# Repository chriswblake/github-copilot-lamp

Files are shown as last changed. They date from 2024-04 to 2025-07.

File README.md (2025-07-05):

# GitHub Copilot Lamp
A fun and playful lamp to match the energy of [GitHub Copilot](https://github.com/features/copilot). It's 3d printable, fairly easy to assemble, WiFi connected and powered by [WLED](https://kno.wled.ge/) and touch!

> This project was inspired by the original [Octolamp](https://github.com/martinwoodward/octolamp). Go check it out!

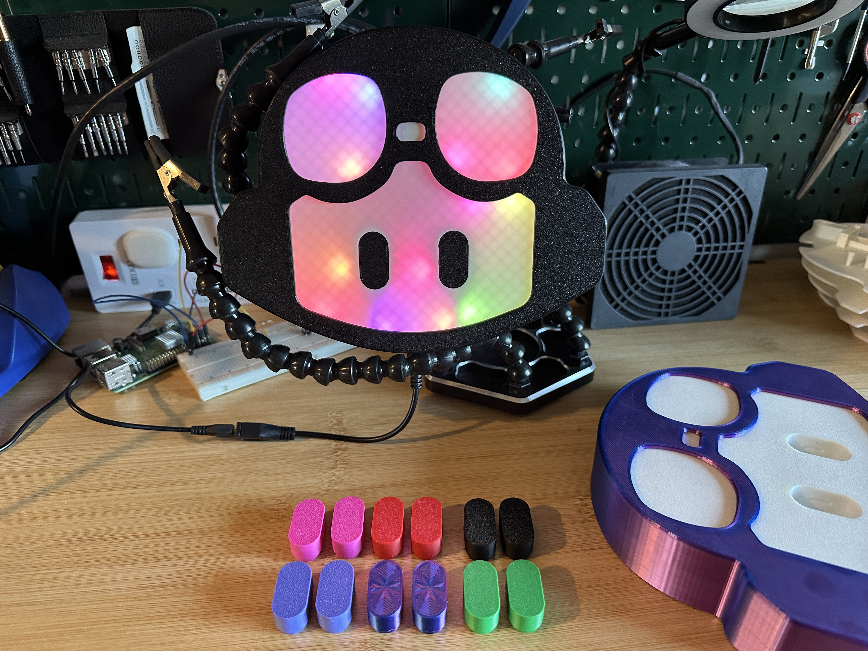
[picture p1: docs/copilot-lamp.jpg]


## How to Use
If you received your lamp prebuilt, is has already been configured and is ready to use. Simply plug it in with a USB cable and power brick with at least 1 amp. The lamp will turn on with an "aurura" like green effect.

### How to Turn on/off
The white spot between the goggles is a touch sensor and provides basic control the lamp. For more advanced control, you can use the WLED app or web interface!

- Automatically turns on at 9am CST.
- Automatically turns off at 5pm CST.

| Single Press | Double Press | Long Press |
| - | - | - |
| Slow Fade Green | Fast Random Rainbow | Off |
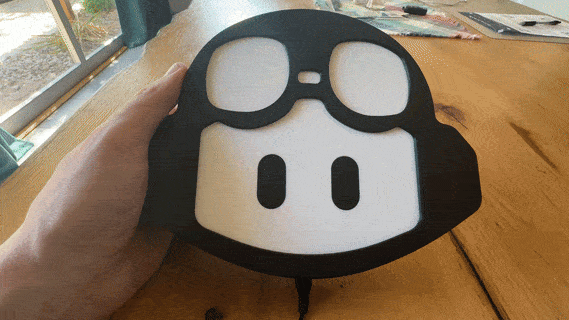
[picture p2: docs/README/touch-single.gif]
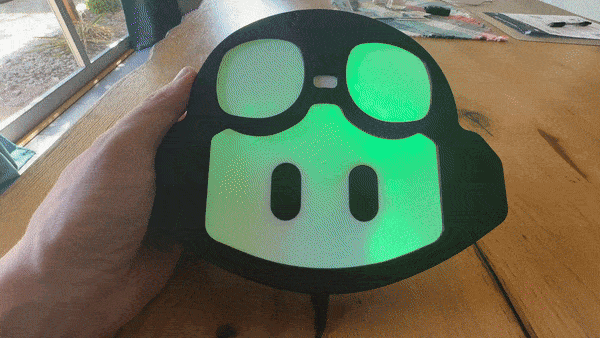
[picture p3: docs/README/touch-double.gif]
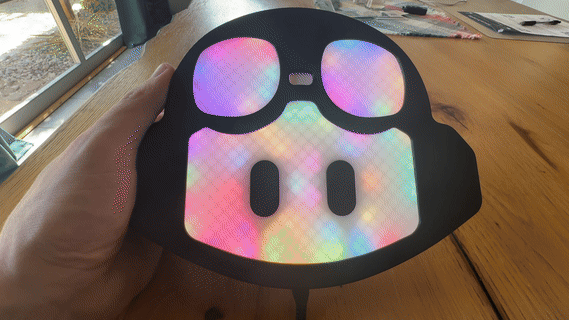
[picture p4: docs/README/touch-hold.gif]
|  |  |  |

### Connect to WiFi
Want full control over your lamp? Connect it to your WiFi network! (2.4ghz only)
If not connected to an existing wifi, it will broadcast a tempory wifi network for setup.

1. On your phone or computer, search for the wifi network `copilot-lamp` and connect to it.
    - Default password is `copilot-lamp` or `wled1234`.
1. Wait a moment and a temporary login-style web browser will appear. If no browser appears, open a web browser navigate to http://copilot-lamp.local.
1. In the top right, click the **Config** gear icon to open the settings menu.
1. Select **WiFi Setup**.
1. Enter you home's wifi name and password. Click **Save & Connect**. Wait a moment for the lamp to restart.
1. Reconnect your phone or computer to your home wifi.
1. Now when connected to your home wifi, you can use the WLED app.
    - [iOS App](https://apps.apple.com/us/app/wled/id1475695033)
    - [Android App](https://play.google.com/store/apps/details?id=com.aircoookie.WLED)
    - Alternately, the lamp can still be accessed in  a web browser by navigating to http://copilot-lamp.local.

<div>
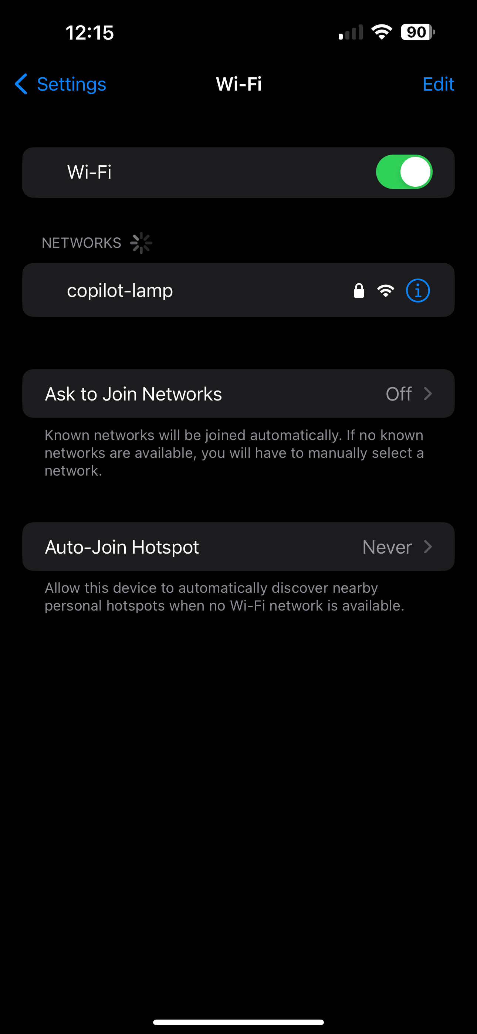
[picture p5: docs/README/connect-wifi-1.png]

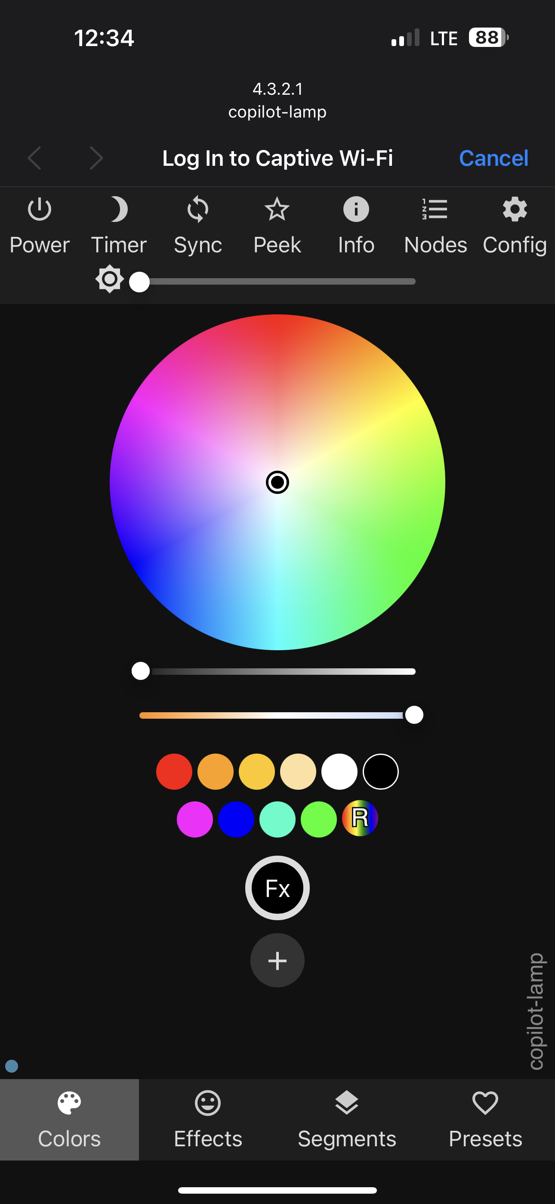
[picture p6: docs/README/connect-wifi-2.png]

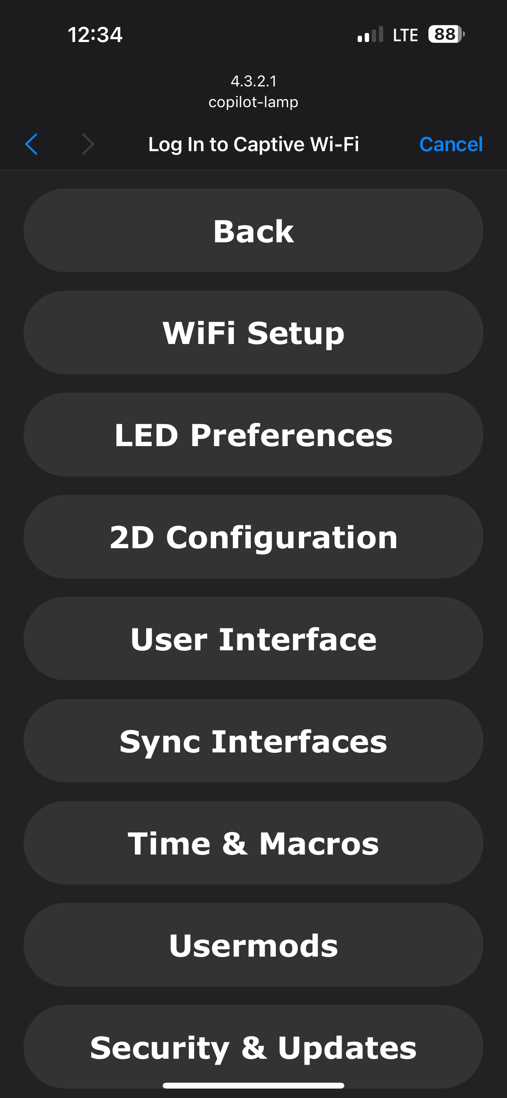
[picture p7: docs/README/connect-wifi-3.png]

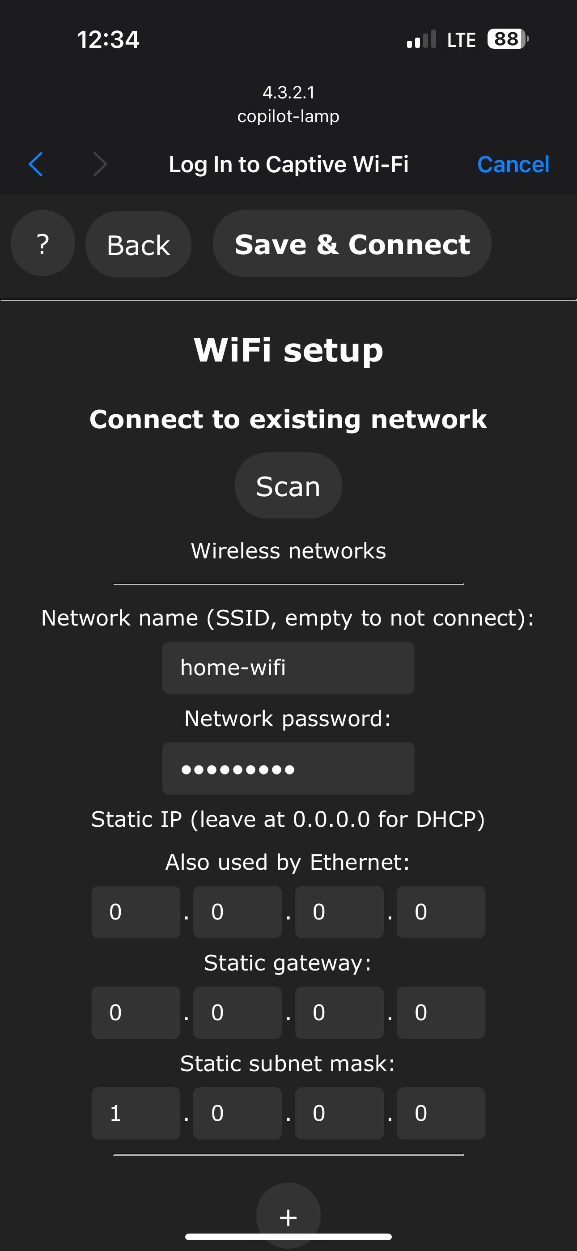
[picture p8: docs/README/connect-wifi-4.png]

</div>

### Change eye color

1. Using a screwdriver, insert the end through the holes in the back of the lamp.  
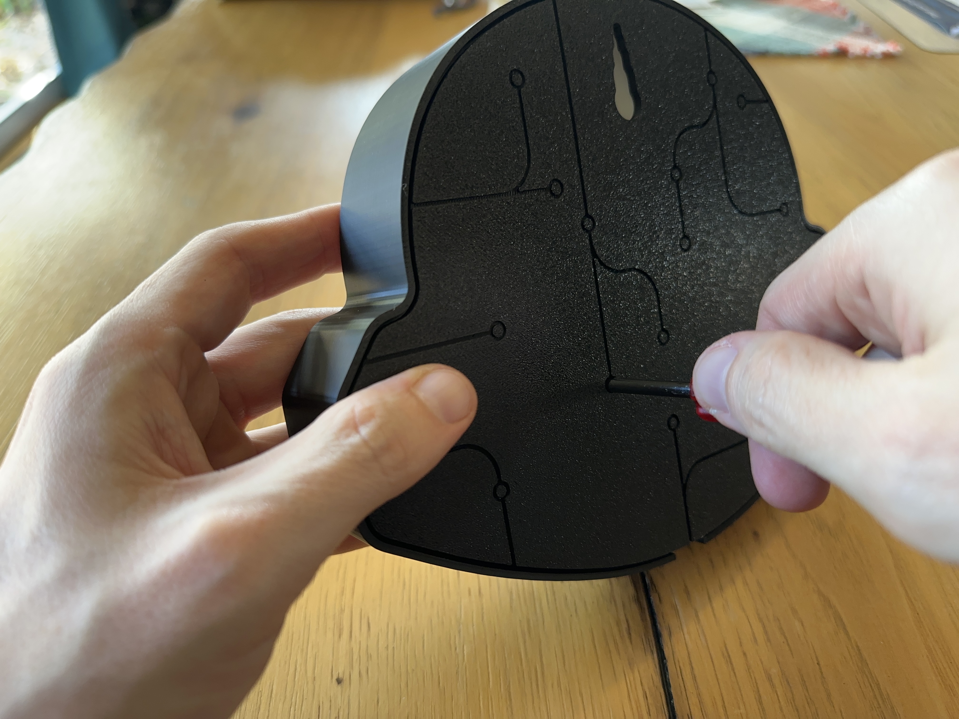
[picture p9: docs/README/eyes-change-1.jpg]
    

1. Continue to push and the eye insert will pop forward.  
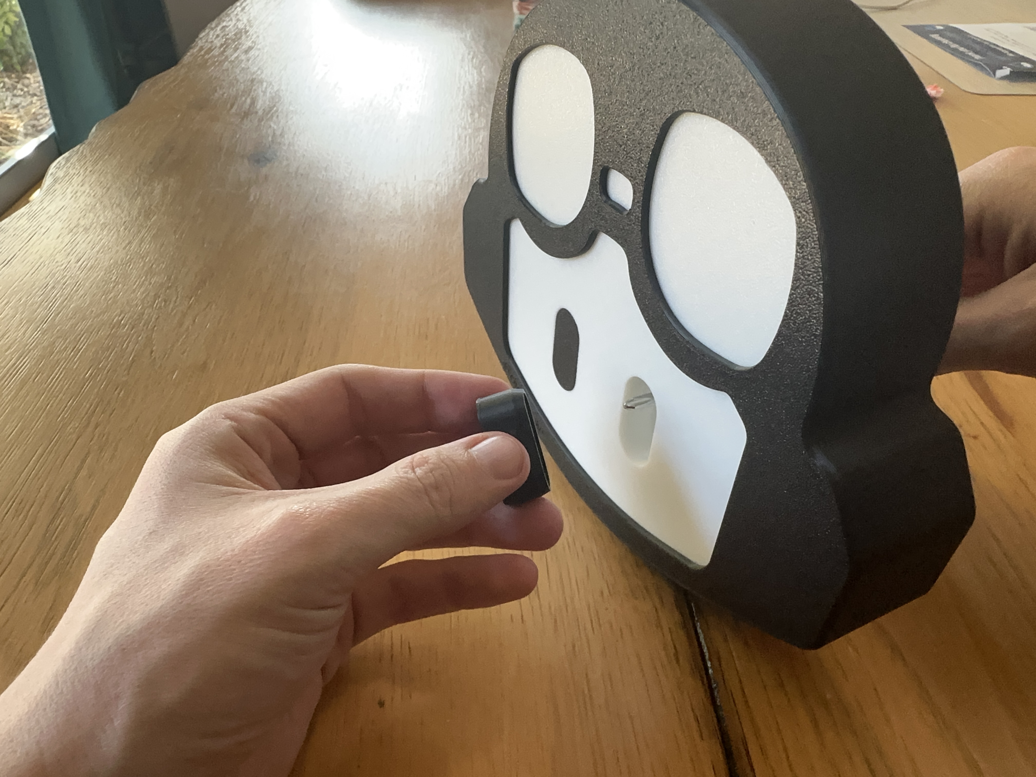
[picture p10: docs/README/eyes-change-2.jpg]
    

1. Insert the other colored eyes!

### Change helmet color (faceplate)

1. Grip the top of the mask and gently push into the white space of the goggles. You will feel the connectors pop out.  
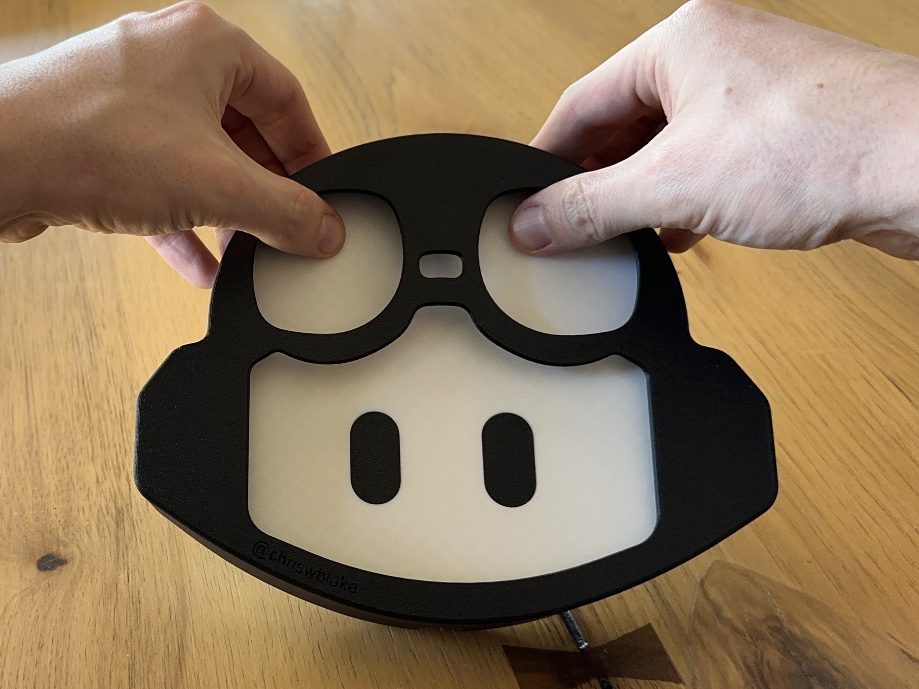
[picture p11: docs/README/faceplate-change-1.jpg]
    

1. Flip the lamp over, and repeat on the other side. Once disconnected, slide the faceplate off.

1. Apply the new faceplate!

## Troubleshooting

### Can't connect to WiFi.
If you aren't able to connect to 'copilot-lamp' or you locked yourself out by entering bad wifi information, you can update the wifi information at the WLED website.

1. Connect the device to your computer using a USB cable.
1. Click 'Install' button. It will detect the lamp already has WLED installed and provide options.
1. Select 'Change WI-FI' and it will scan for nearby options.
1. Enter your wifi password and wait a moment.
1. Click 'Visit Device' and it will navigate to the webpage view.

# Build your own 🤓
That's cool and all, but how do I make one?!  
Check out the [build your own](docs/build-your-own.md) page for a step-by-step guide. 🧑‍🚀

Making it for someone else? How kind of you! 💚 Check out the [gift a friend](docs/gift-a-friend.md) page to create an awesome unboxing experience! 🤩

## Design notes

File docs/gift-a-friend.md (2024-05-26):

# Guide: Gift a friend 💚
The copilot lamp is meant to be shared, and... who doesn't want an awesome unboxing experience. 🥰

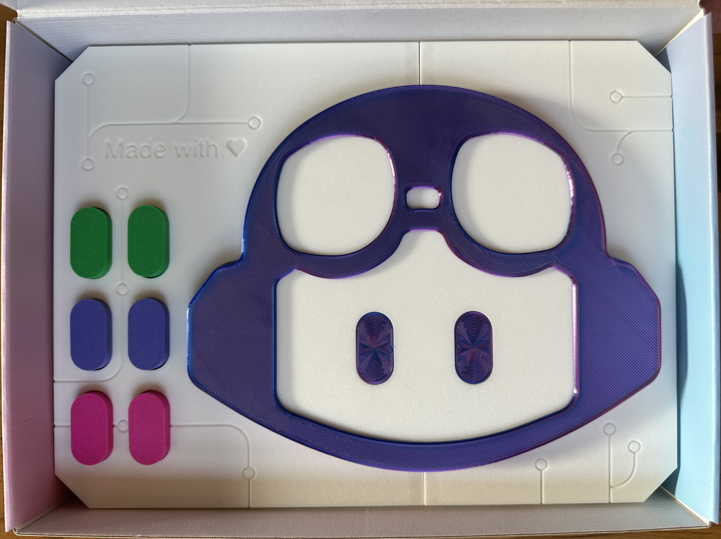
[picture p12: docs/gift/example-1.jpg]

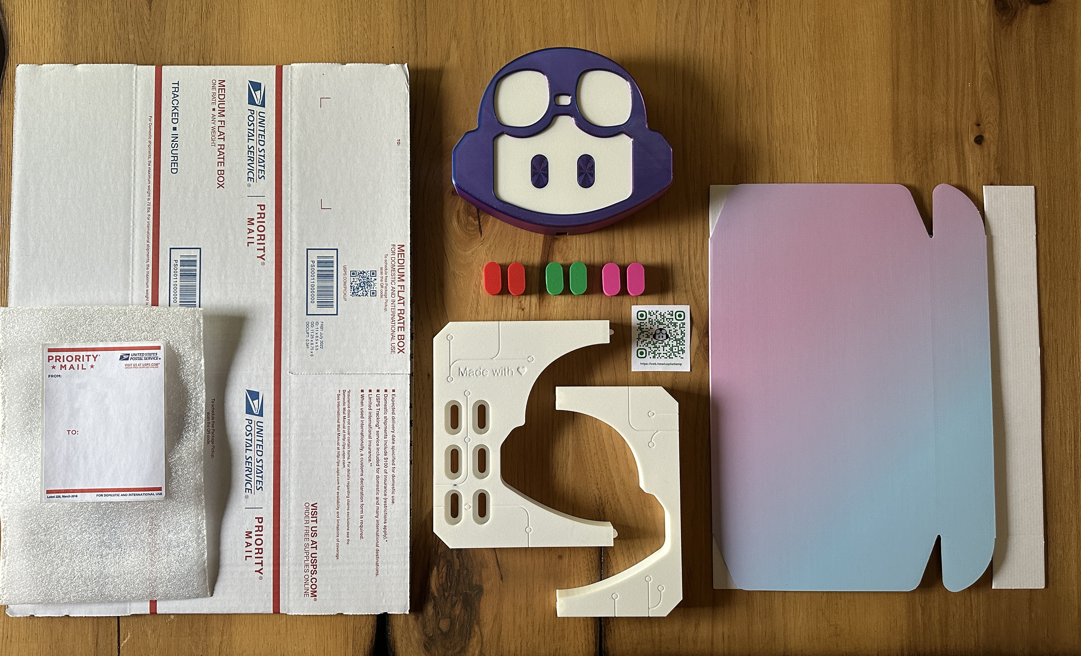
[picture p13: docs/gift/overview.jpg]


### Materials
- White PLA Filament [[US]](https://us.store.bambulab.com/products/pla-basic-filament?variant=41078274687112)
- Beautiful Gradient Purple Box (11x8x2) [[US]](https://www.amazon.com/dp/B0B7JB5KC9)
- USPS Medium Size Shipping Box, Top Loading [[US]](https://store.usps.com/store/product/shipping-supplies/priority-mail-flat-rate-medium-box-1-P_O_FRB1)
- Packing Foam
- Packing Tape

# Instructions

## 1. Print the parts
The .STL files for all of the printable shipping protector are in the `/models` folder.

- No supports are required.
- Any infill is fine. No special settings are required.
- For a matte look, consider a textured plate. [[US]](https://us.store.bambulab.com/products/bambu-dual-sided-textured-pei-plate)

| Image | Part | Description |
| -- | -- | -- |
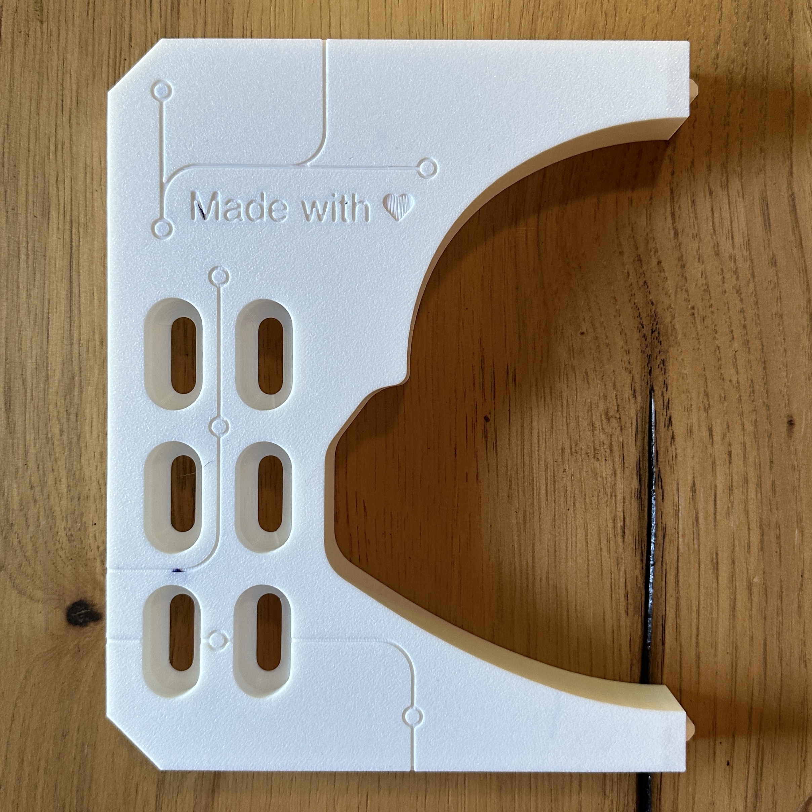
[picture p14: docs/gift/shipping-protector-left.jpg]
 | Shipping Protector (left) | Connects with the right piece to hold the position of the lamp in the box. Has slots for holding additional eye colors. Also indirectly teaches owner how to swap eyes colors. |
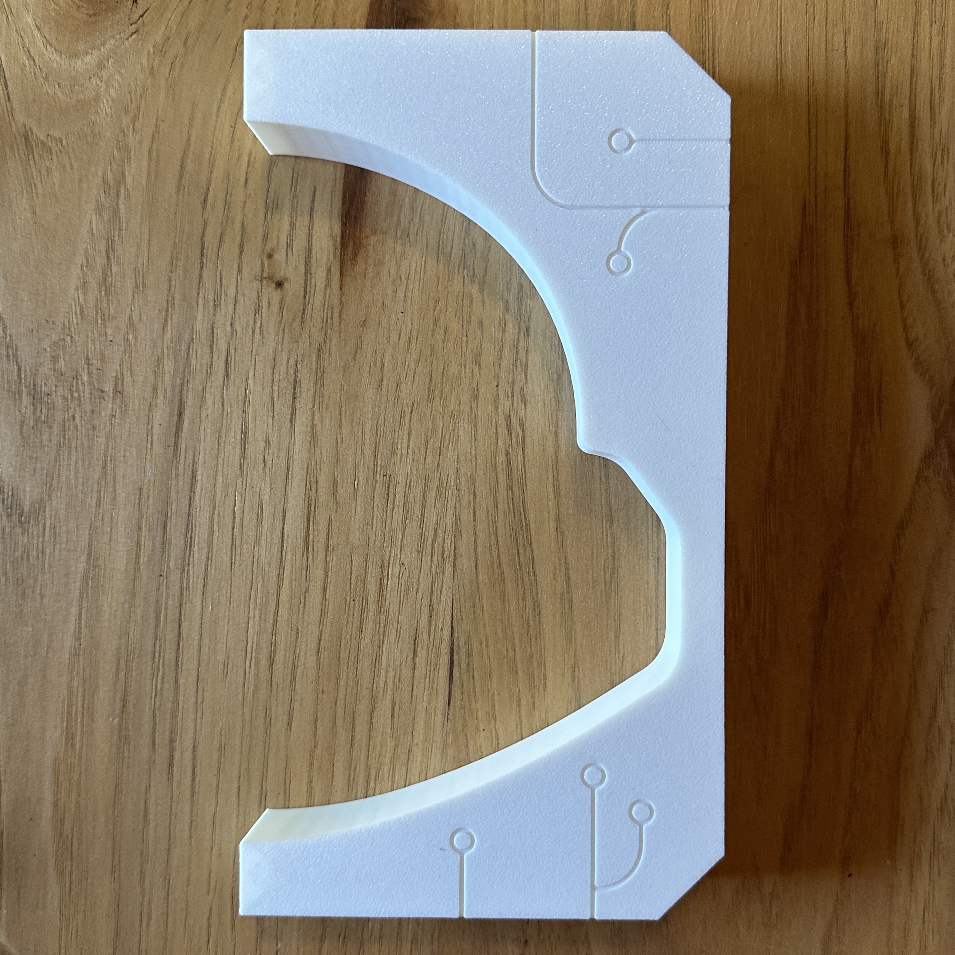
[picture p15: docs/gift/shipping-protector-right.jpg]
 | Shipping Protector (right) | Connects with the left piece to hold the position of the lamp in the box. |
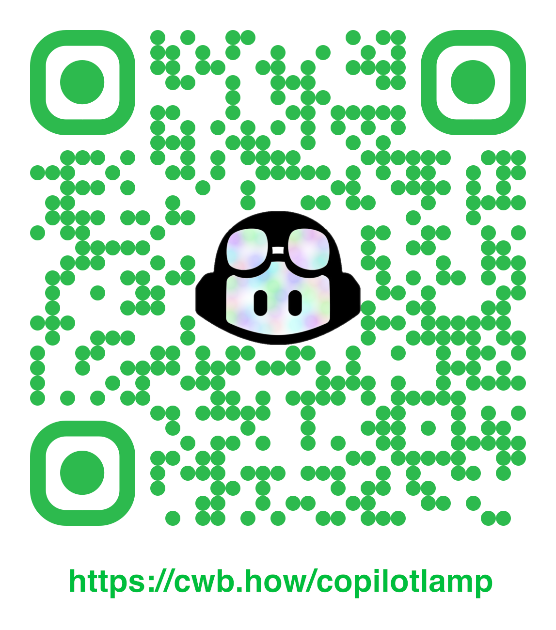
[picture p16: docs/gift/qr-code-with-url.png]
 | User Instructions QR Code | When scanned, directs user to main README for basic usage instructions. Obviously just normal 2D printing. 😉 |

## 2.  Prep the Copilot Lamp box

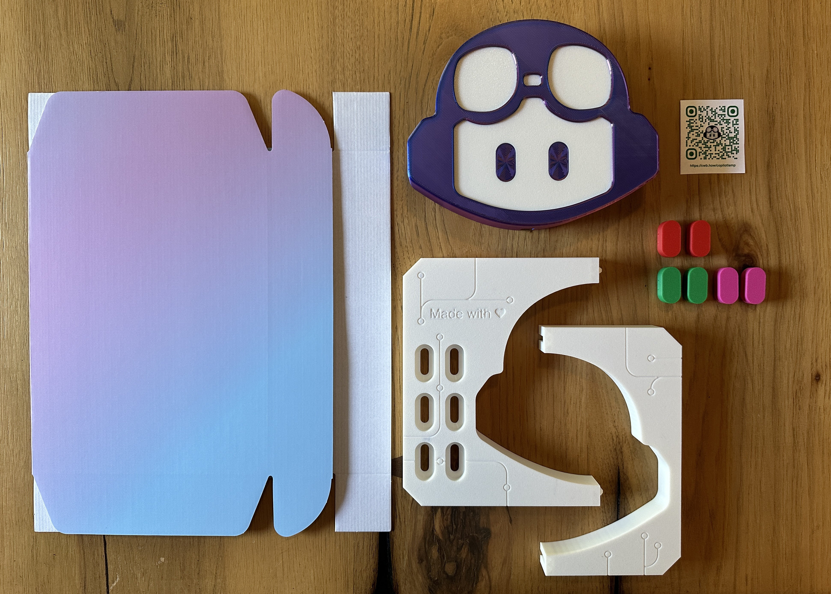
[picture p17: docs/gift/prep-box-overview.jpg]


1. Ensure the tabs of the front and back are inward and fold the sides down. The side's have tabs that slip into the slot to keep the shape.
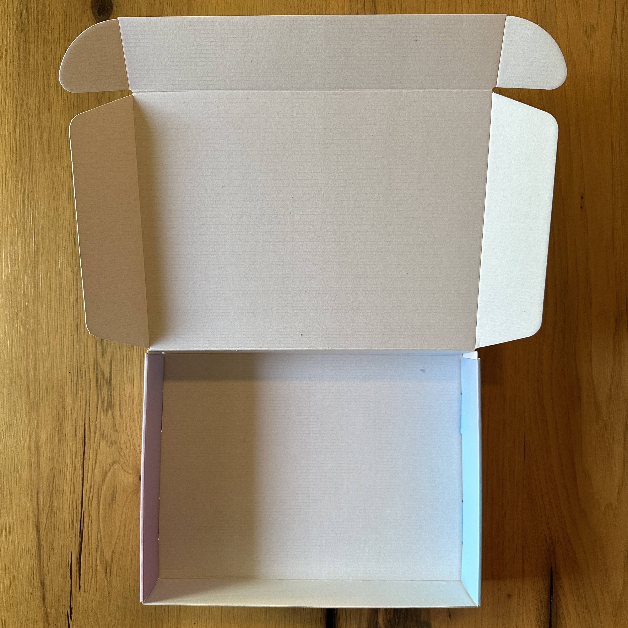
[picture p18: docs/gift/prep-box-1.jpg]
    

1. Connect the left shipping protector and right shipping protector together.
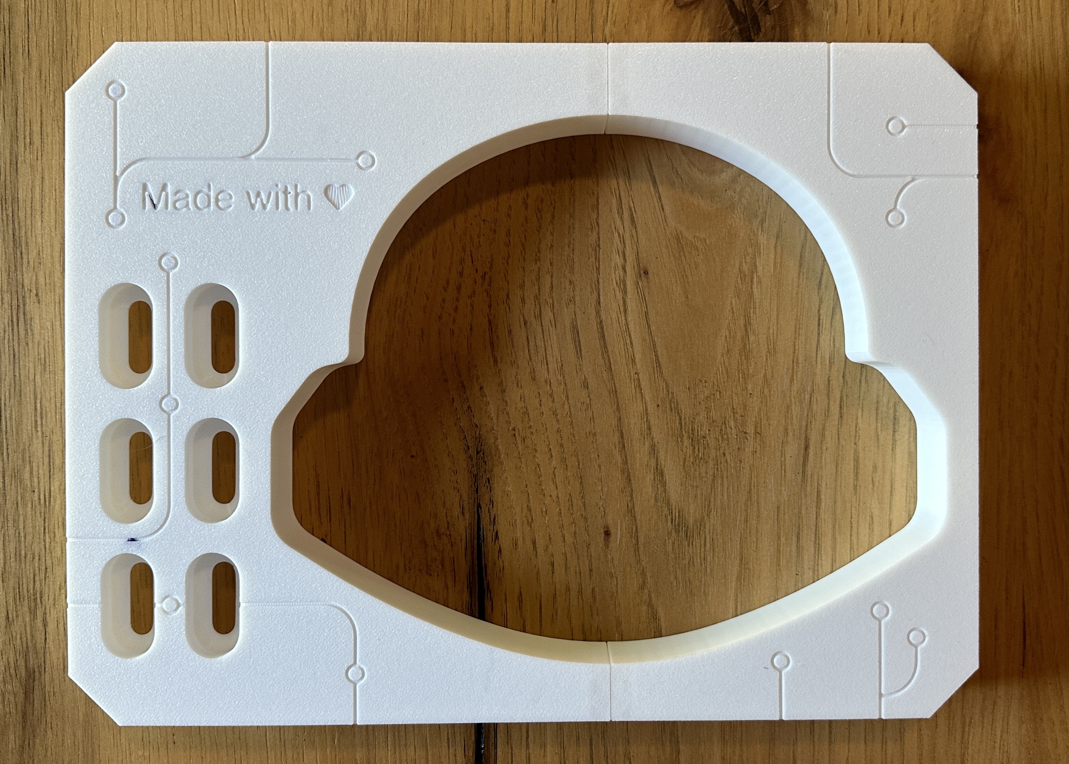
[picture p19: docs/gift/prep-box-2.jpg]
    

1. Insert the shipping connector into the box.
    > Note: It may appear loose. The gaps will be filled when the top is closed.
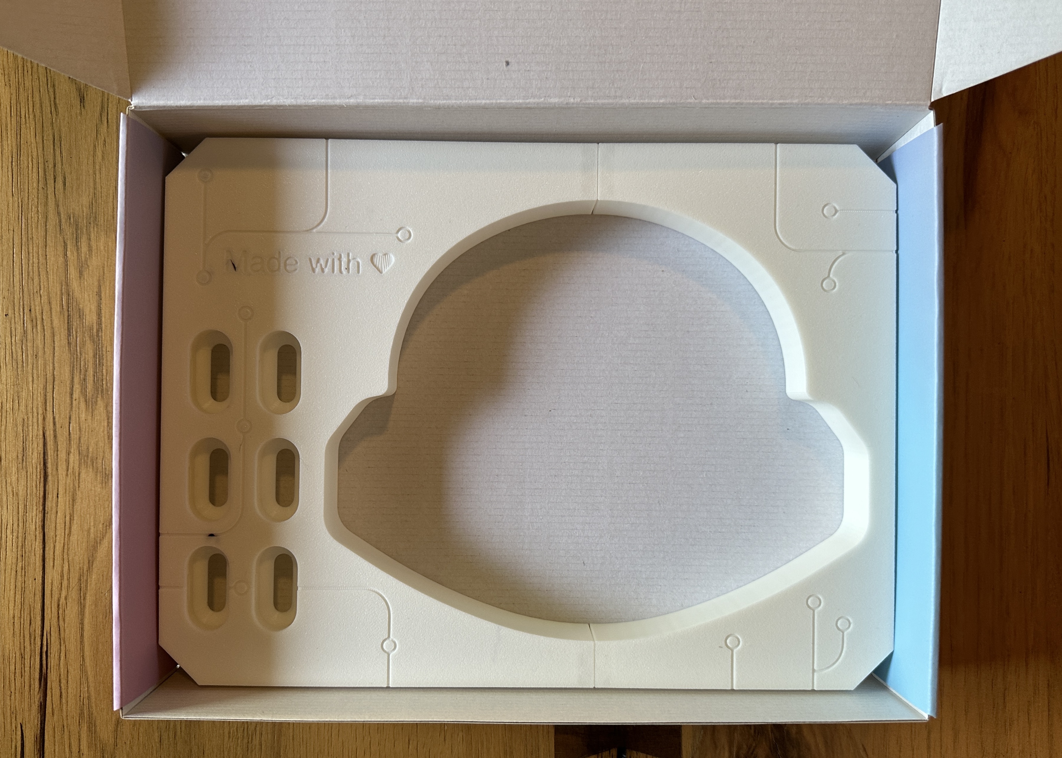
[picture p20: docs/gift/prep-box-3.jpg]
    

1. Insert the lamp.
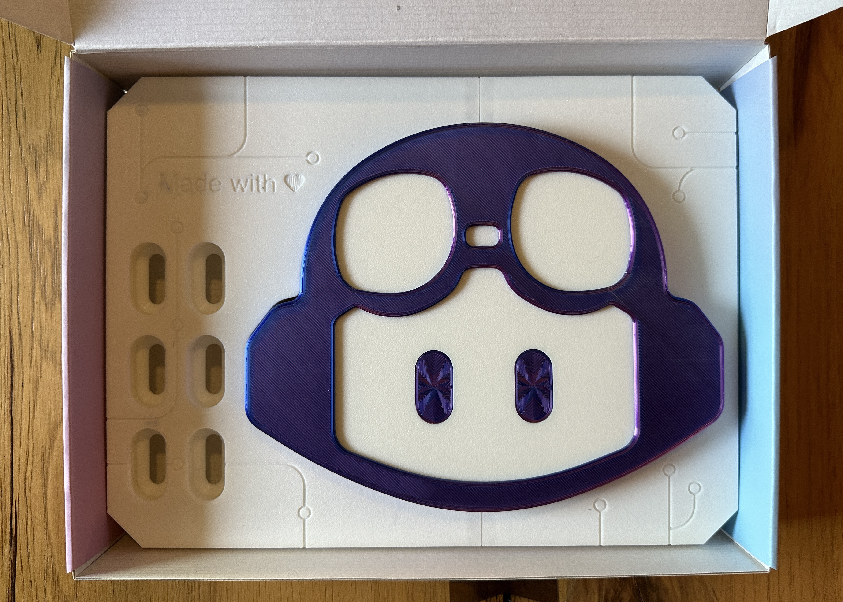
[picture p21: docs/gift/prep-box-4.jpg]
    

1. Pick some fun extra eye colors. Snap them into the holders.
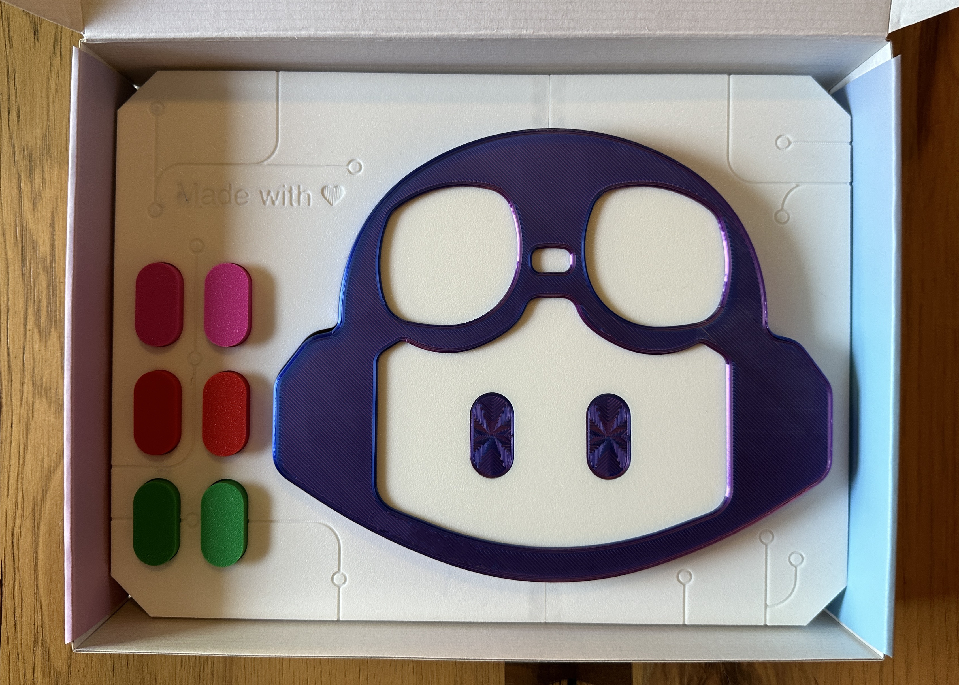
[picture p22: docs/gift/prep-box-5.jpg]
    

1. Add a sheet of protective foam.
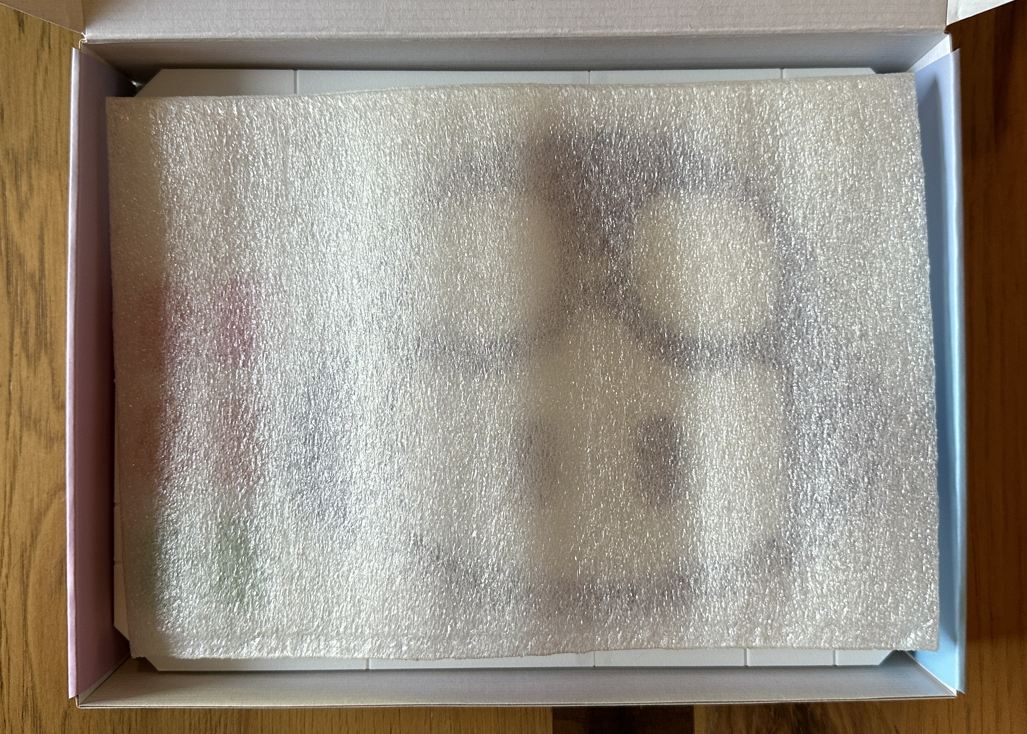
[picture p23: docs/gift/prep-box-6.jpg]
    

1. Add the QR Guide.
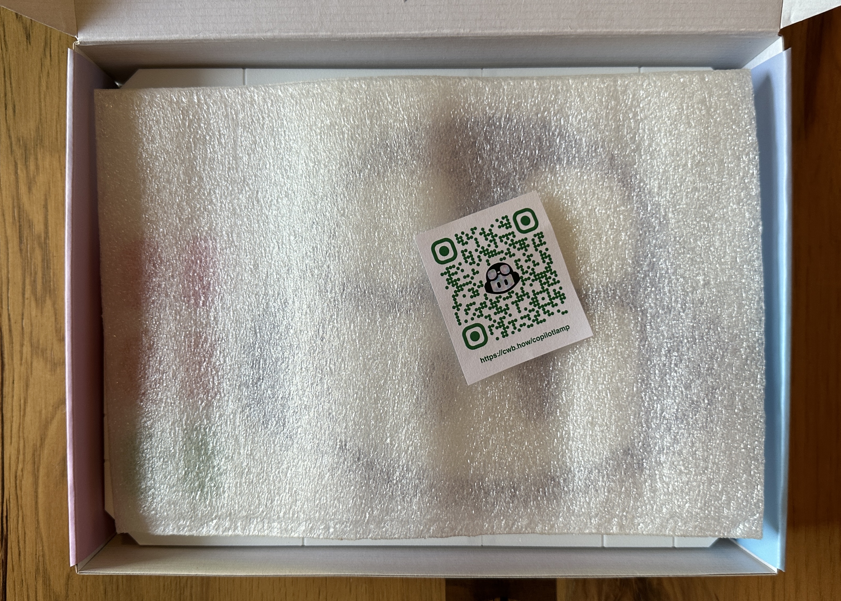
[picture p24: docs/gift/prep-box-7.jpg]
    

1. Close the box. Smile for a job well done! 🤓
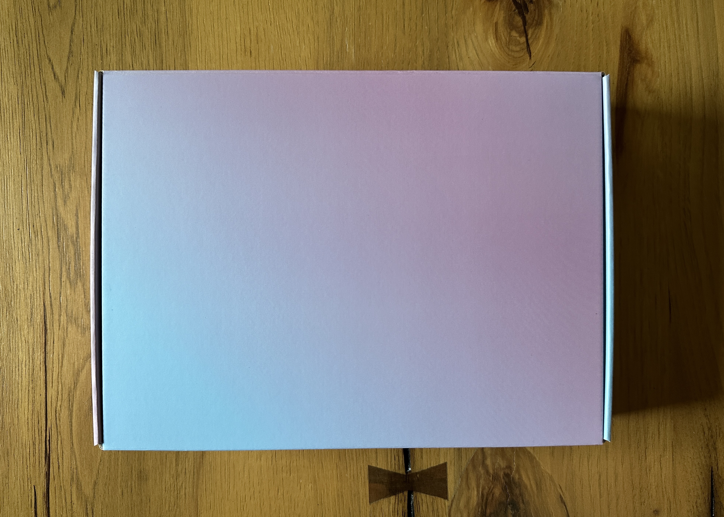
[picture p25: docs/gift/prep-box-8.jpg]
    

## 3. Ship the gift

1. Fold the USPS shipping box and tape the bottom side.
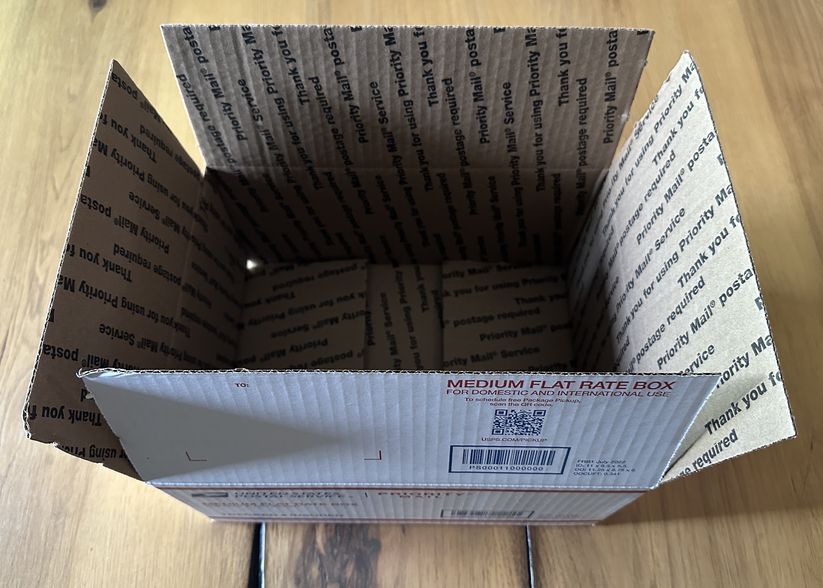
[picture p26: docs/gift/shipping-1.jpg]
    

1. Add some shipping protection to the bottom.
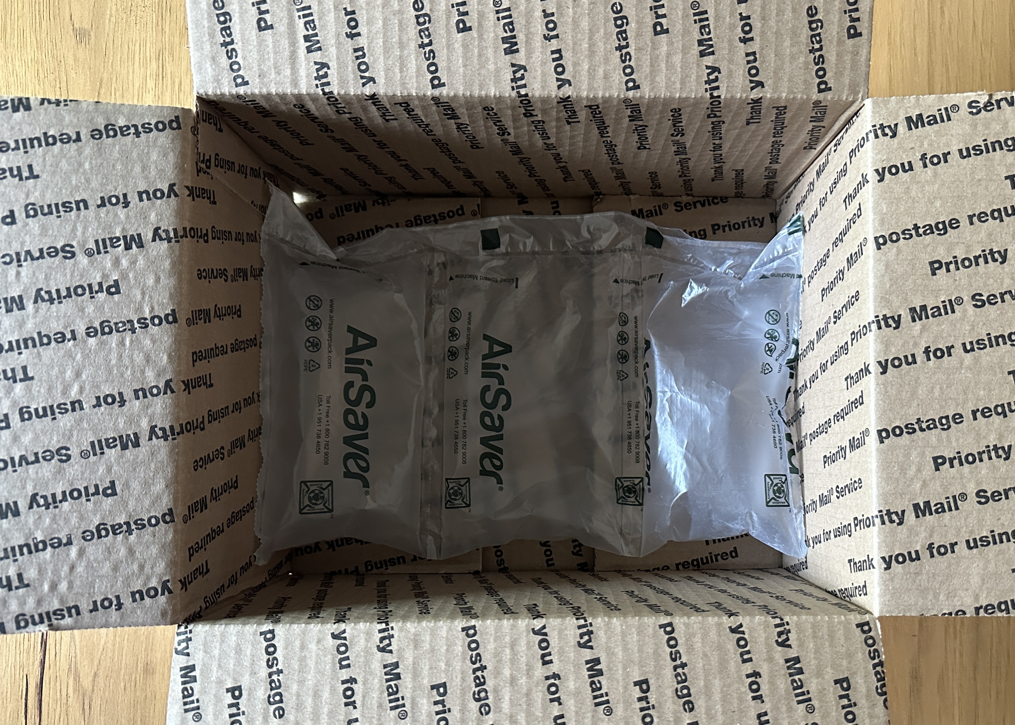
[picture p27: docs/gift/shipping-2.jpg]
    

1. Insert the box with your GitHub Copilot lamp.
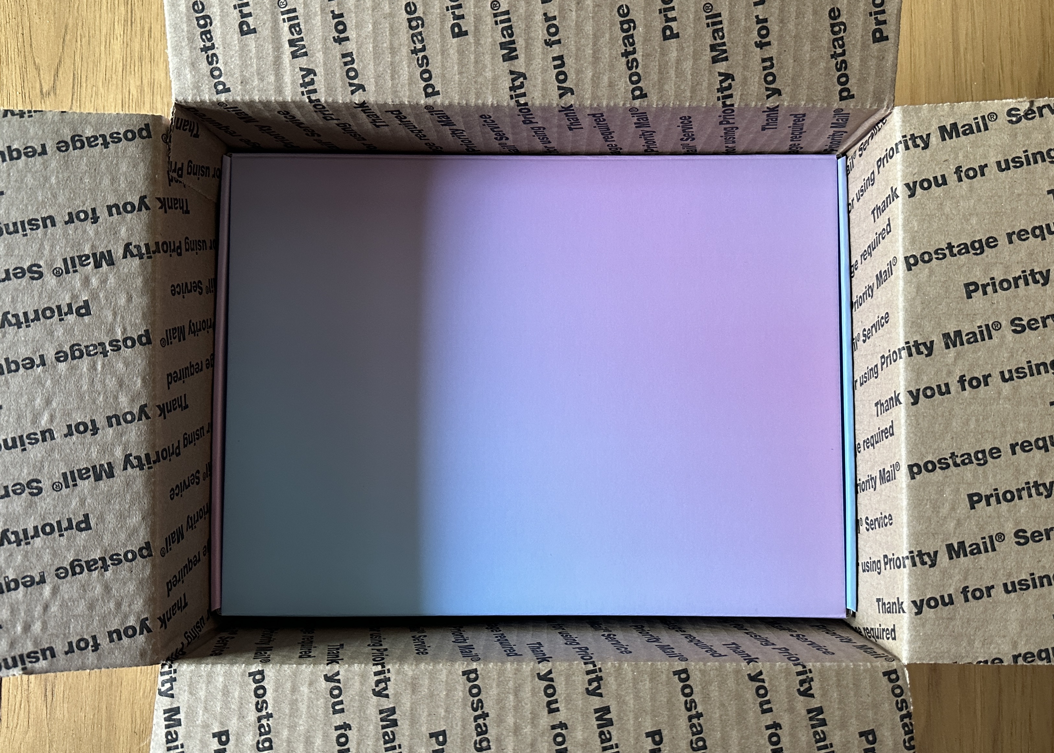
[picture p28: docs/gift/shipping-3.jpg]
    

1. Add some more shipping protection.
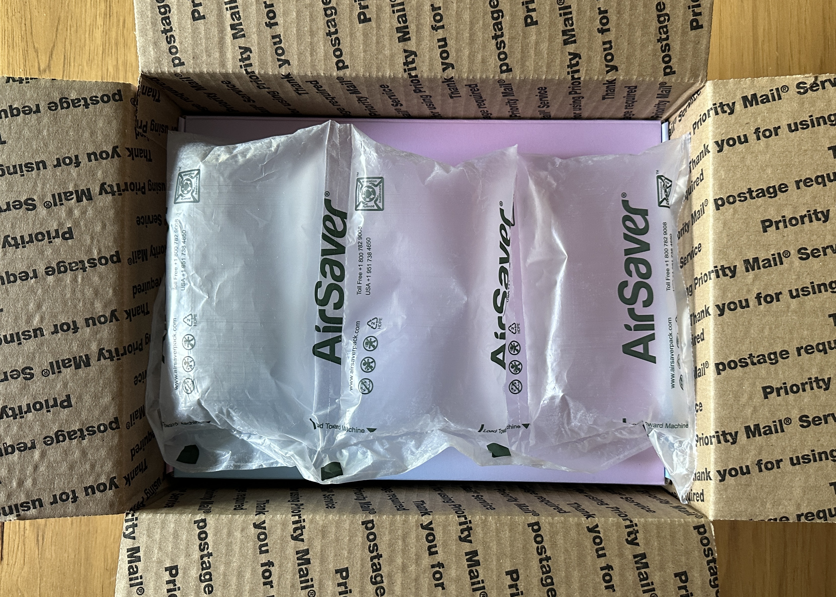
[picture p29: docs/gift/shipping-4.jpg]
    

1. Close the box folds and tape it shut.
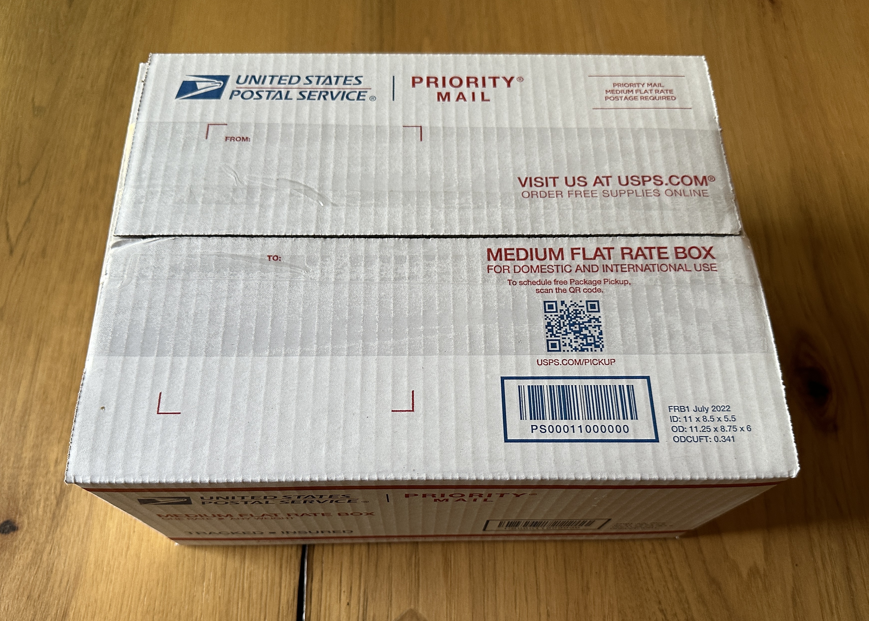
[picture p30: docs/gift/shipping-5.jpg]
    

1. Fill out the address sticker.
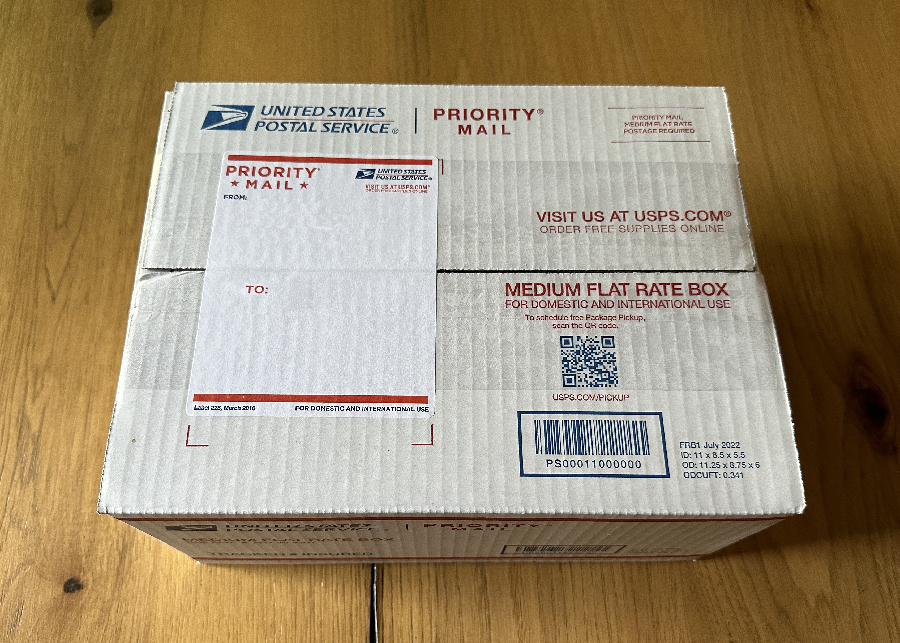
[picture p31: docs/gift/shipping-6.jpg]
    

1. Take it to the post office!

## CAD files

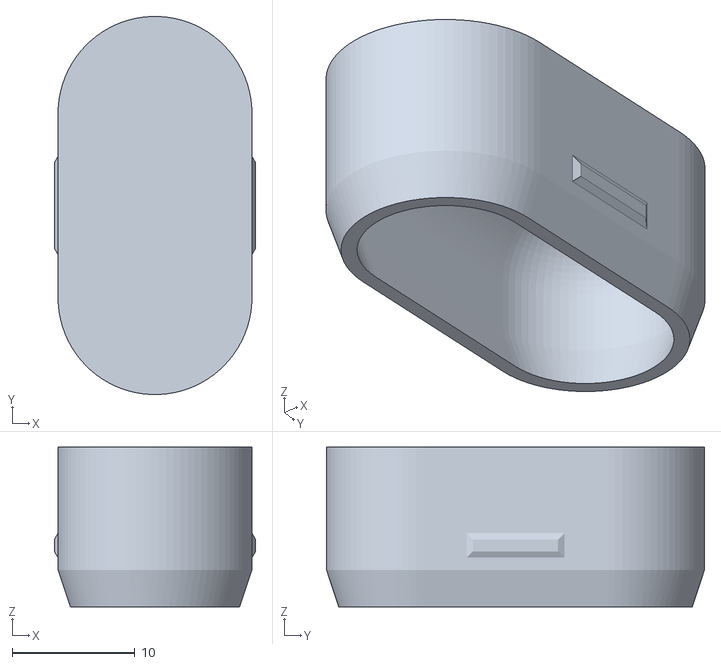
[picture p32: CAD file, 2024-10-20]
models/eye.stl
16.4 x 30.8 x 13.0

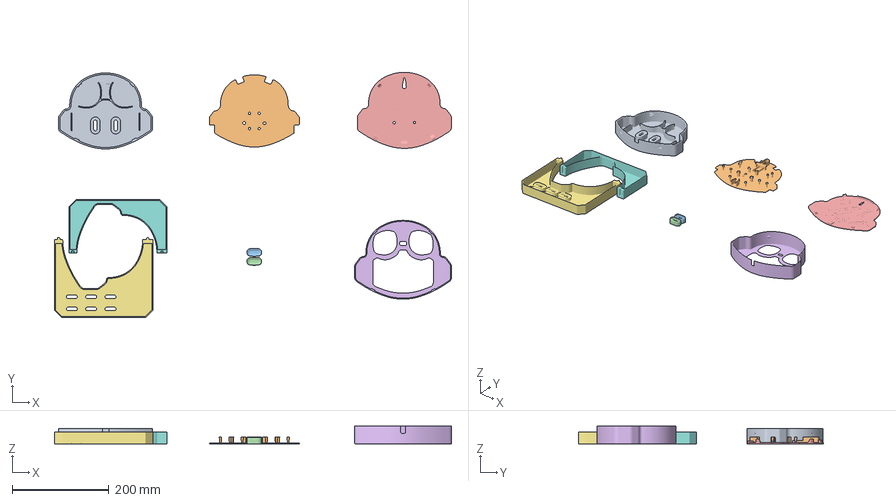
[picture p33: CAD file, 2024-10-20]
models/gh-copilot-lamp.3mf
819.8 x 506.6 x 37.0 mm
led-chamber.stl
electronics-plate.stl
eye.stl x 2
backplate.stl
faceplate.stl
shipping-protector-left.stl
shipping-protector-right.stl

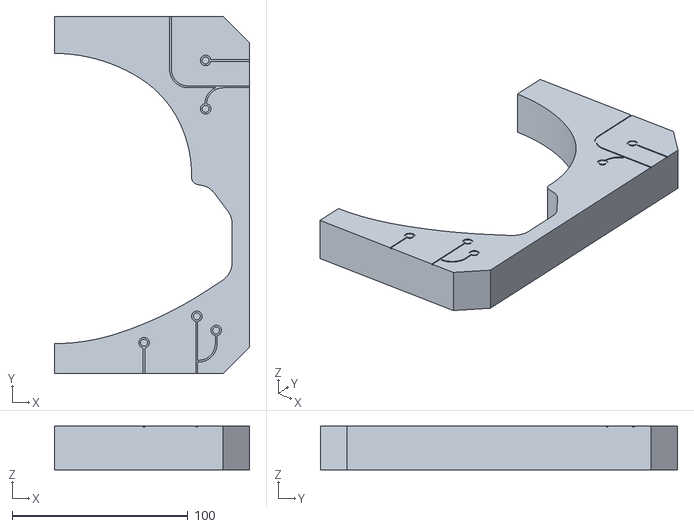
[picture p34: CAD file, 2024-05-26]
models/shipping-protector-right.stl
111.0 x 203.0 x 25.0

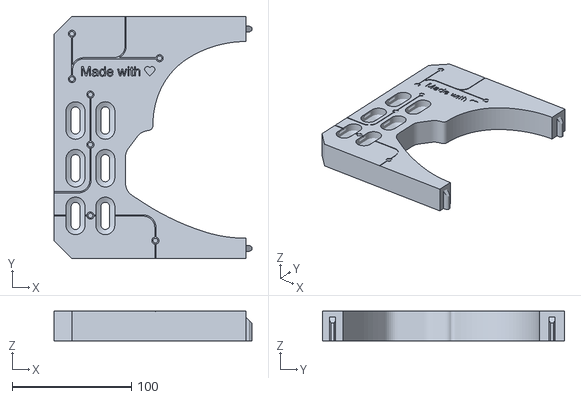
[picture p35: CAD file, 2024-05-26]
models/shipping-protector-left.stl
166.0 x 203.0 x 25.0

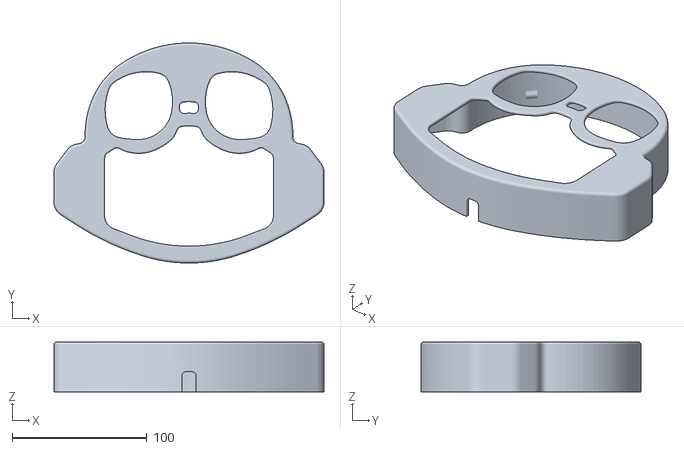
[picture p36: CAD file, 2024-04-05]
models/faceplate.stl
200.0 x 163.0 x 37.0

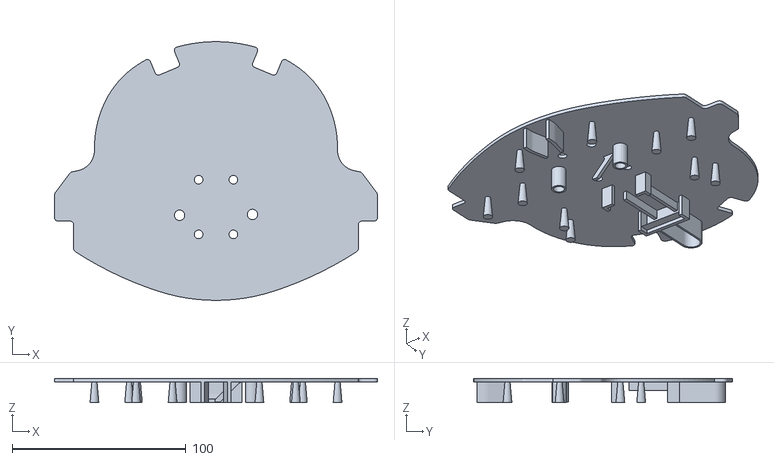
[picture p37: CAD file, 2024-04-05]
models/electronics-plate.stl
186.0 x 149.0 x 14.0

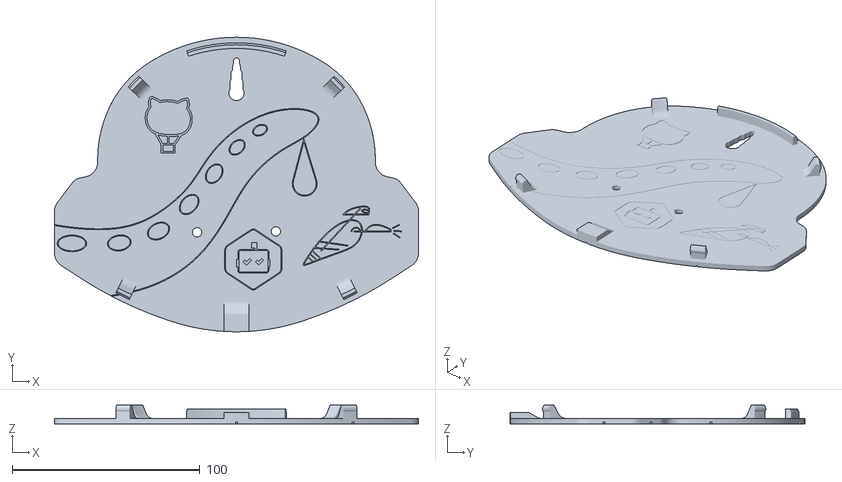
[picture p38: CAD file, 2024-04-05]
models/backplate.stl
194.0 x 157.0 x 10.1

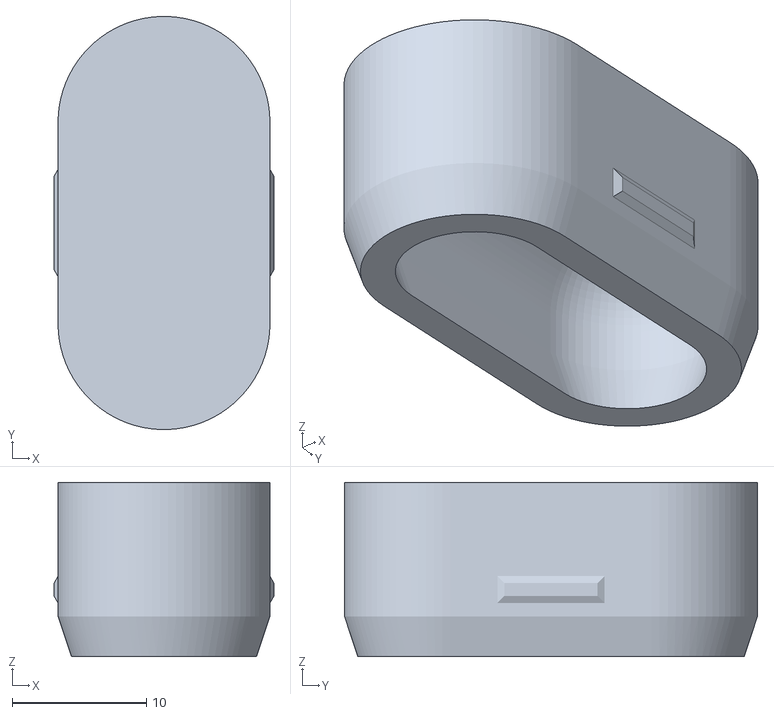
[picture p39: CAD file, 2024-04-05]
models/eye-2mm.stl
16.4 x 30.8 x 13.0

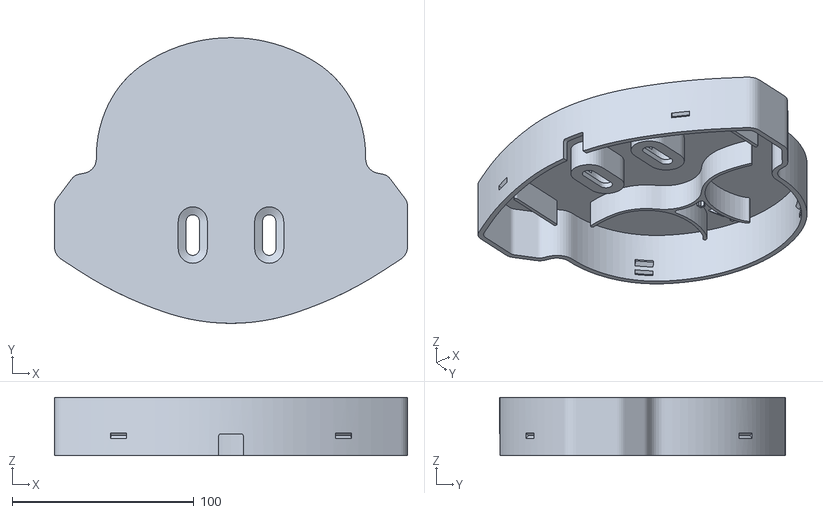
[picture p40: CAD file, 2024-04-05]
models/led-chamber.stl
194.0 x 157.0 x 32.0

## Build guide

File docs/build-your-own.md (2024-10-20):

# Guide: Build Your Own 
The copilot lamp is fairly easy to assemble with a bit of soldering. The hardest part is patiently waiting for all the parts to print! 😉

In short, it is a few 3D printed parts, a microcontroller, some LEDs and a few wires to connect it all together.

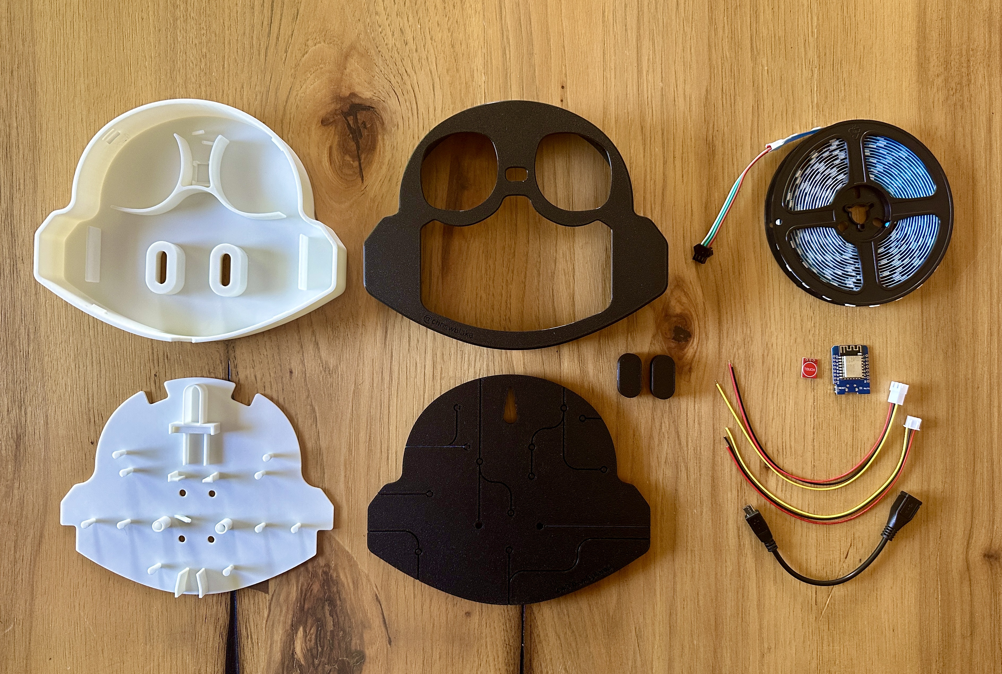
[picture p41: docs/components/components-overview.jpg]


## Prep Work and Sourcing Parts

### Materials
- Black PLA Filament [[US]](https://us.store.bambulab.com/products/pla-basic-filament?variant=41078274654344)
- White PLA Filament [[US]](https://us.store.bambulab.com/products/pla-basic-filament?variant=41078274687112)
- 60 LEDs (1 meter) - WS2812B Addressable LED Light Strip [[US]](https://www.amazon.com/dp/B097379J1V)
- ESP8266 Microcontroller micro-USB + WiFi [[US]](https://www.amazon.com/dp/B081PX9YFV)
- TTP223 Capacitive Touch Sensor [[US]](https://www.amazon.com/dp/B01D1D0FLG)
- JST Cable (white, 26awg) [[US]](https://www.amazon.com/dp/B0CF2BTYSK)
- Short Micro-USB Extension [[US]](https://www.amazon.com/dp/B0791ZZ3HG)
- (optional) 3/8" Shrink Tubing [[US]](https://www.amazon.com/dp/B07FK17W6B)
- (optional) JST Cable (black, 20awg) [[US]](https://www.amazon.com/dp/B071H5XCN5)
- (optional) Long micro-USB cable. [[US]](https://www.amazon.com/dp/B0CGDPS336)
<!-- - JST Socket [[US]](https://www.amazon.com/dp/B0BMDZR7RZ) -->

### Tools
- Soldering Iron
- 3D Printer

> [!NOTE]
> **Tip:** Don't have a 3D printer? Check if your local library has a makerspace. They might be able to print the parts for you! 🤩

# Instructions
The lamp is designed to be assembled by hand, minus the small amount of soldering. It's printed with regular PLA filament on a printer with at least 200x200mm print area.

## 1. Print the parts
The .STL files for all of the printable parts are in the `/models` folder.

- No supports are required.
- Avoid sparse infill for the backplate to strengthen the connectors.
- Avoid sparse infill for the LED chamber if you don't want to see a pattern through the glowing.
- For a textured look, consider a textured plate. [[US]](https://us.store.bambulab.com/products/bambu-dual-sided-textured-pei-plate)
- The `eye.stl` model may break with more brittle filaments like PLA Silk. There is an `eye-2mm.stl` file for this but it is more difficult to remove.

> [!Tip]  
> The backplate, faceplate, and eyes don't have to be black.
> Try printing them in another color or with fun multicolor or shiny filament! 🦄 🤩

| Image | Part | Description |
| -- | -- | -- |
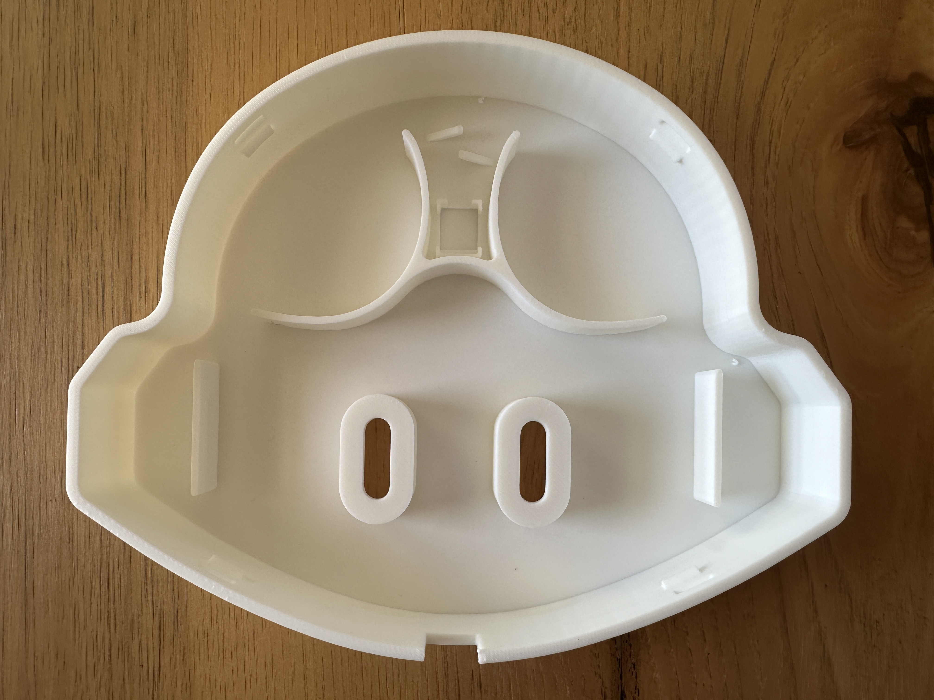
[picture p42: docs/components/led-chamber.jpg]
 | LED Chamber | The part that glows, where the LEDs are attached. |
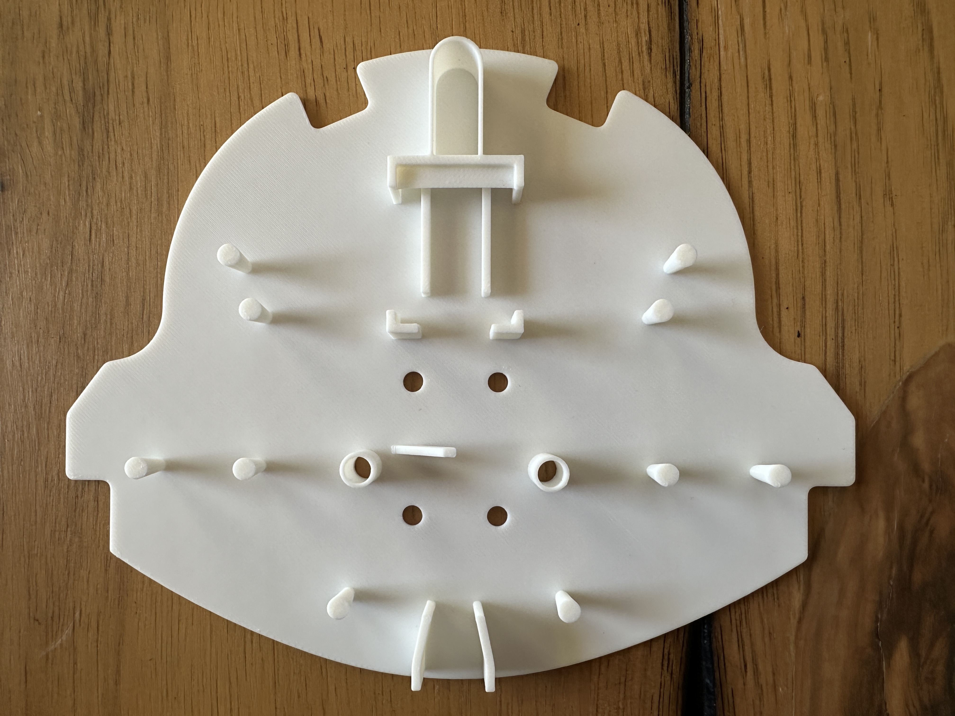
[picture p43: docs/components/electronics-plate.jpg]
 | Electronics Plate | Sits inside the LED chamber for the microcontroller and cable management. |
 | Backplate | The back cover of the LED chamber. |
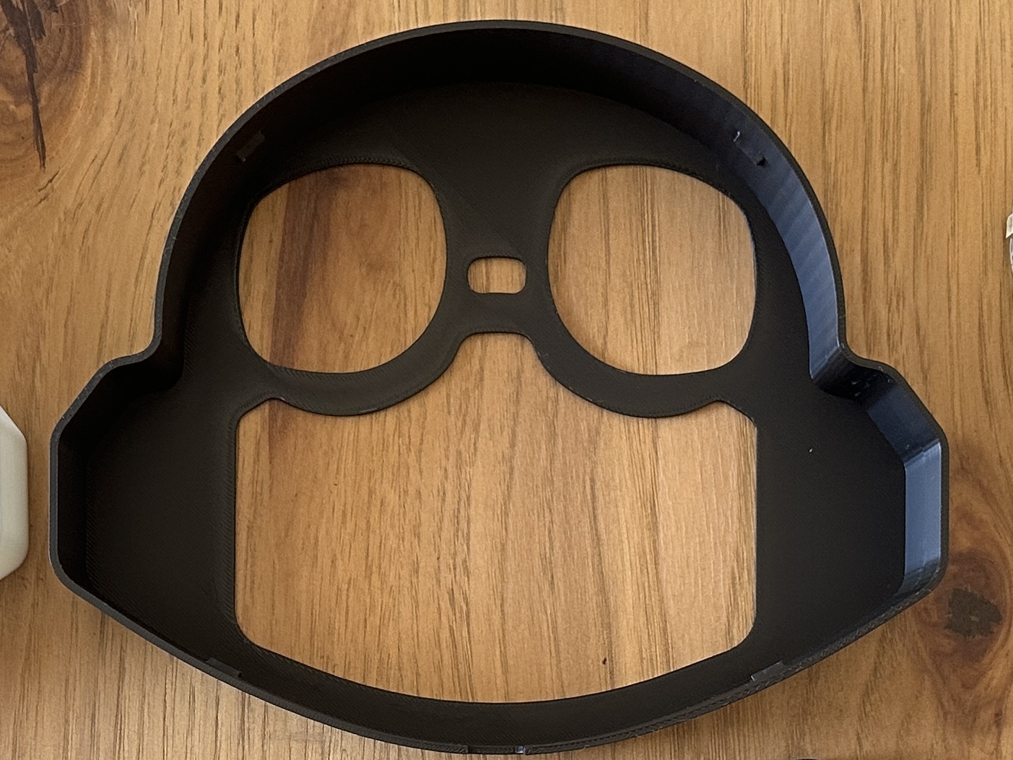
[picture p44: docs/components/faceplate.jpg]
 | Faceplate* | The outer shell for changing color. |
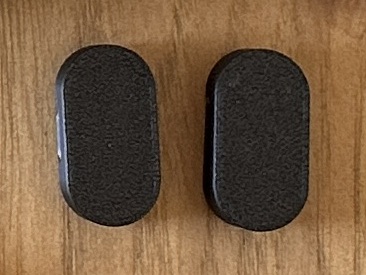
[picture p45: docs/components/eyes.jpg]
 | Eyes | Interchange eye inserts for the face of the LED chamber. |

> [!NOTE]  
> If you know how to use Autodesk Fusion, you can add your GitHub handle to the chin of the faceplate. The 3D model already has a feature. Just change the text. 🤯

## 1. Install Software
If you order the microcontrollers from the provided link, there
is a good chance that 1 of the 5 boards will be bad.
It's important to start with installing the software.

1. Connect the microcontroller to your computer using a USB cable.
1. Open a web browser and navigate to the [WLED install page](https://install.wled.me/).
1. In the drop down, ensure version `0.15` is selected.
1. Click the **Install** button and a window will appear.
Select the USB serial device.
1. Follow the instructions and wait a few minutes for the install.
    - If this seems to have trouble, try a different board.
1. When asked, enter your WiFi details.
    - Accessing the device locally is required to upload the configuration.
1. When the install is finished, click the **Visit Device** button.
1. On the device's main page, in the top right, click the **Config** button.
1. At the bottom, select **Security and Updates**
1. Scroll to the bottom and look for the backup options.
1. Install the presets using the [`/wled-config/wled_presets_playlists.json`](../wled-config/wled_presets_playlists.json) file.  
This will do the following:
    - Install playlist 1 - Slow effects. (Single press action)
    - Install playlist 2 - Fast random effects. (Double press action)
    - Install preset 3 - LEDs off (Hold 2 seconds action)
1. Install the device configuration using the [`/wled-config/wled_config_60_led_with_touch.json`](../wled-config/wled_config_60_led_with_touch.json) file.  
This will do the following:
    - Set the device to use 60 LEDs and max 1 amp power.
    - Configure use of the touch sensor.
    - Assign the touch sensor to the playlists.
    - Configure a timer option to turn on the lamp at 9am and off at 5pm.
    - Set it to broadcast a WiFi network named `copilot-lamp`, if no WiFi is found.
    
## 2. Pre-Assembly and Testing

### LED Strip
1. Keeping the plug end, cut the 5 meter LED strip to 60 LEDs (1 meter).

> [!WARNING]  
> The ~1 meter length is more important than the 60 LEDS.
> If the strip is too long it may not fit. If it is too short, then parts may not glow. 😕

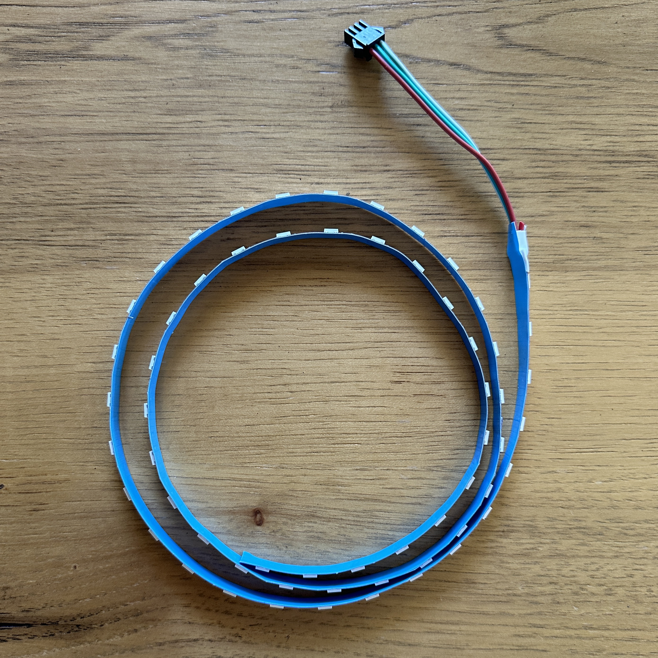
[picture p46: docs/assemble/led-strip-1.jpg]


### Touch Sensor
1. Attach a JST lead cable (plug side) to the contacts of the touch sensor.
    - Black Wire: GND (ground)
    - Yellow Wire: I/O (communication)
    - Red Wire: VCC (3.3v power)

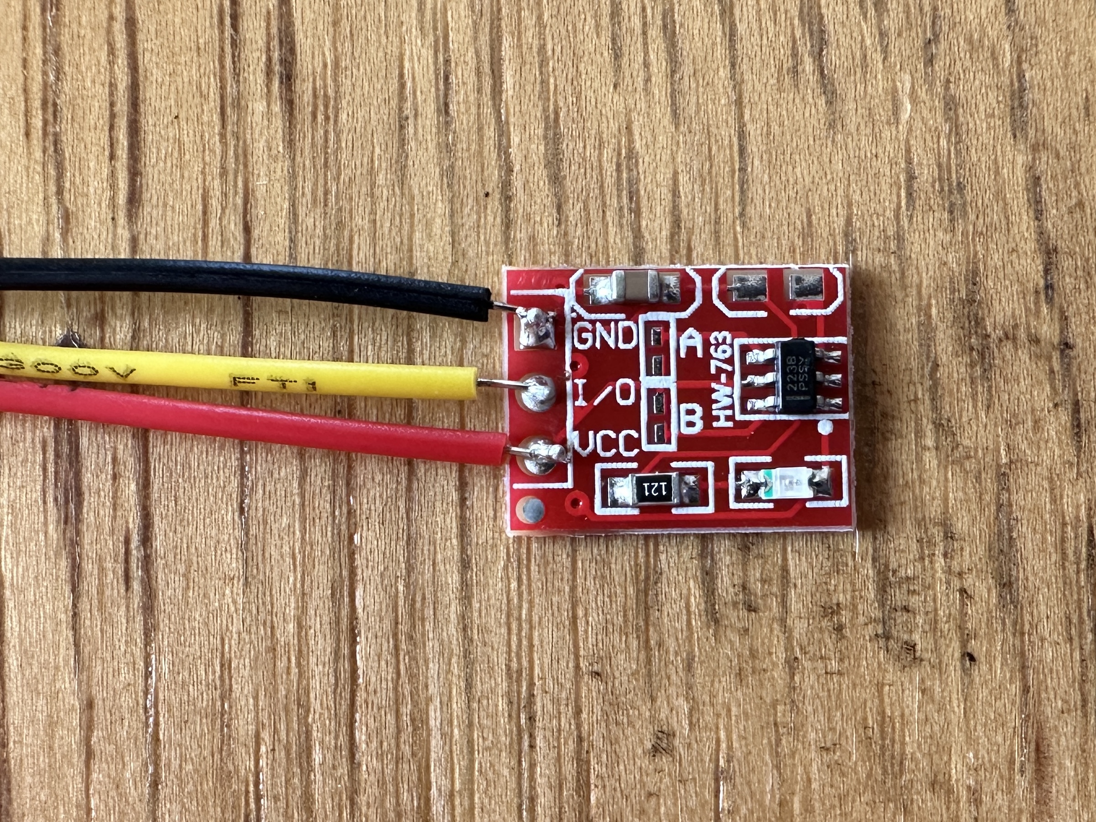
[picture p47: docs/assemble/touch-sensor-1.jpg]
    
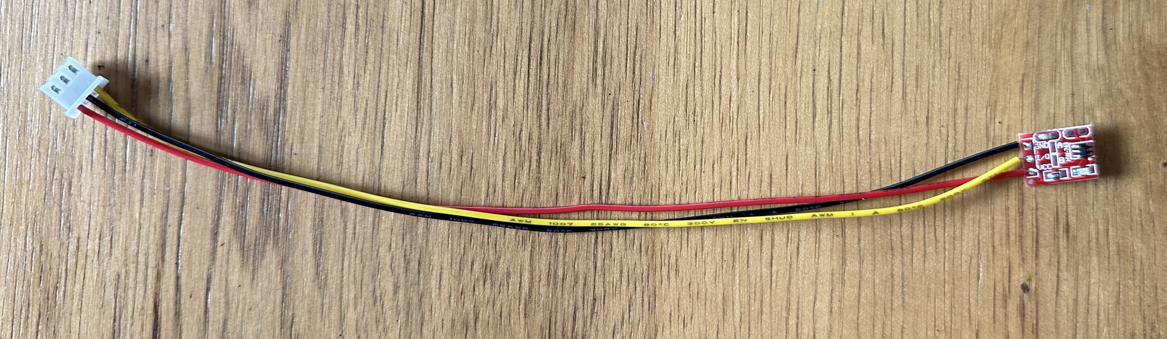
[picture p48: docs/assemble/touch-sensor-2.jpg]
    

### LED Lead Cable
1. Your LED strip may have come with a simple controller. Remove the socket end from it or from the 5 meter LED strip.

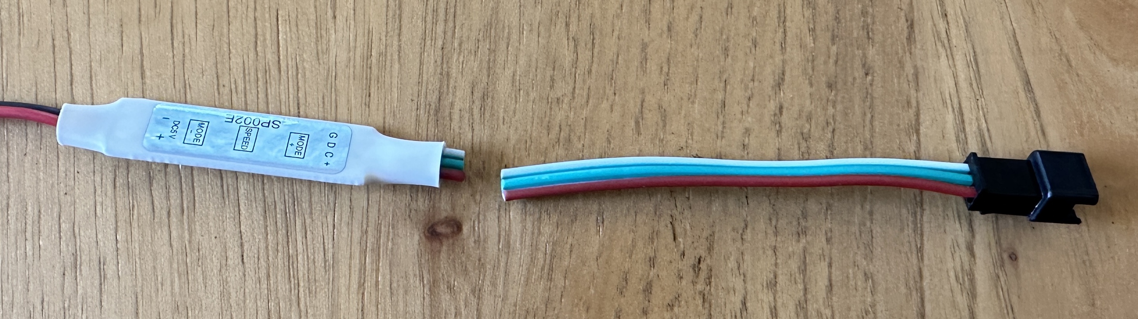
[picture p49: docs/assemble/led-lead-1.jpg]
    
    or
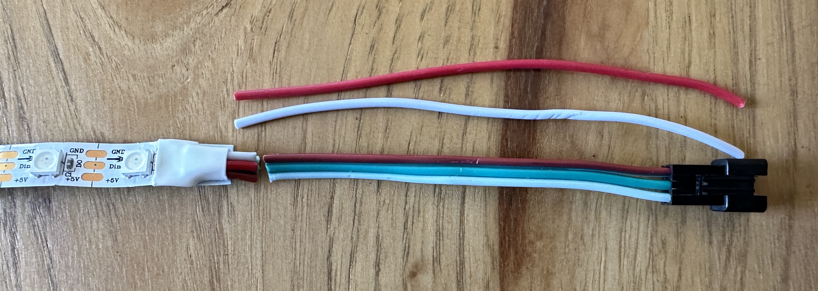
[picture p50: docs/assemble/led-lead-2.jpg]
    

### Touch Lead Cable
1. Shorten a JST lead cable (socket side). Leave the black wire longer, about the width of the microcontroller.
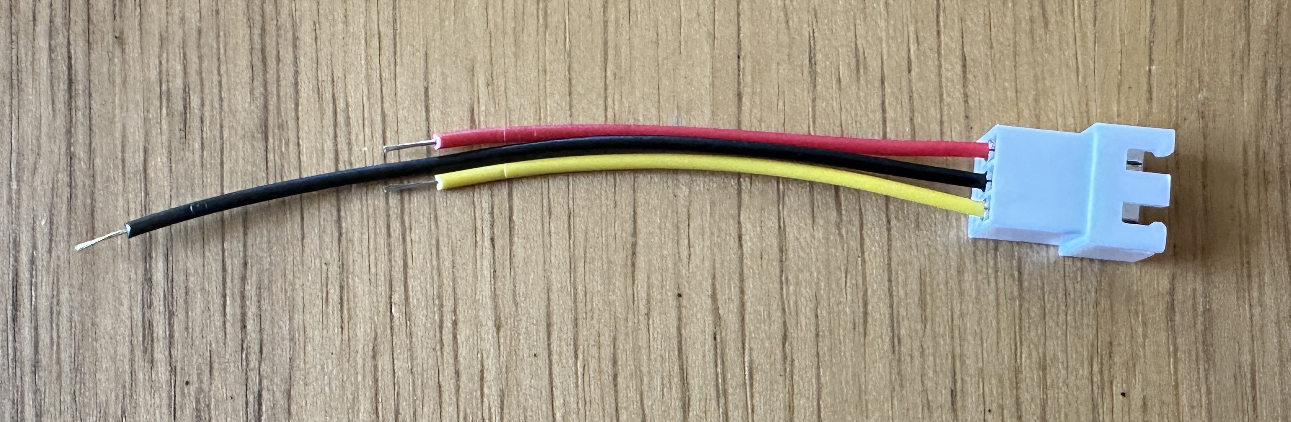
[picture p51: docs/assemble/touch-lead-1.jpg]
    

### Microcontroller
1. Attach the LED lead cable (socket side) to the microcontroller.
Make sure the cables come out of the side with the wifi module.
    - Red Wire: 5V (power)
    - White Wire: G (ground)
    - Green Wire: D4 (digital)

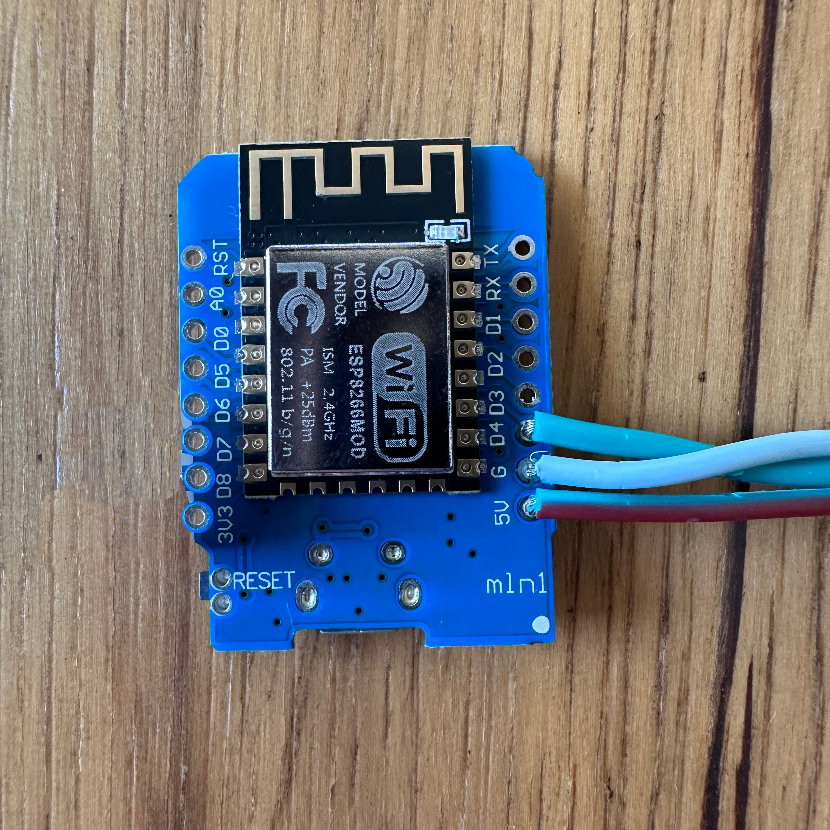
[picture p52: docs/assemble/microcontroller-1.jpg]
    
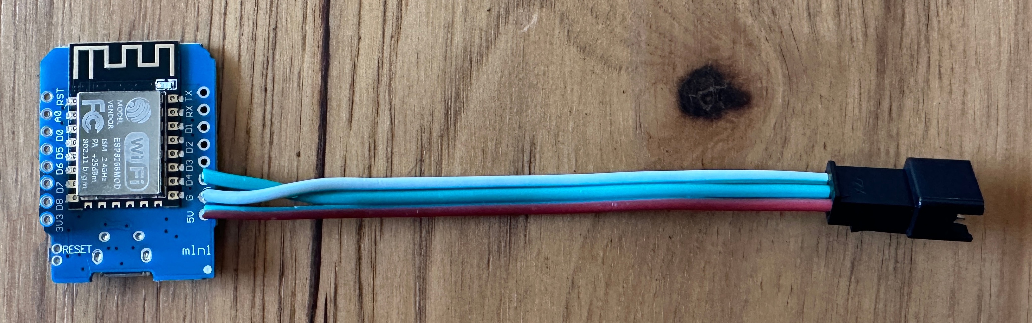
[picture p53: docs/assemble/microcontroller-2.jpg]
    

1. Attach the Touch Sensor lead cable (socket side) to the microcontroller.
Make sure the cables come out of the side with the wifi module.
    - Red Wire: 3V3 (power)
    - White Wire: G (ground) - Note, it is on the other side.
    - Green Wire: D7 (digital)

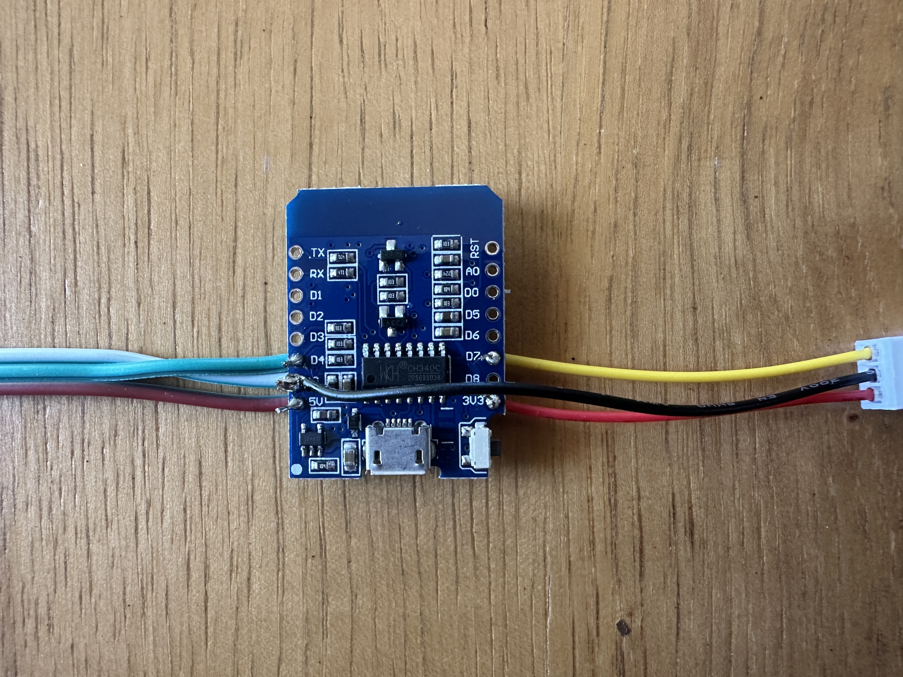
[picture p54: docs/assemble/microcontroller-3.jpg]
    
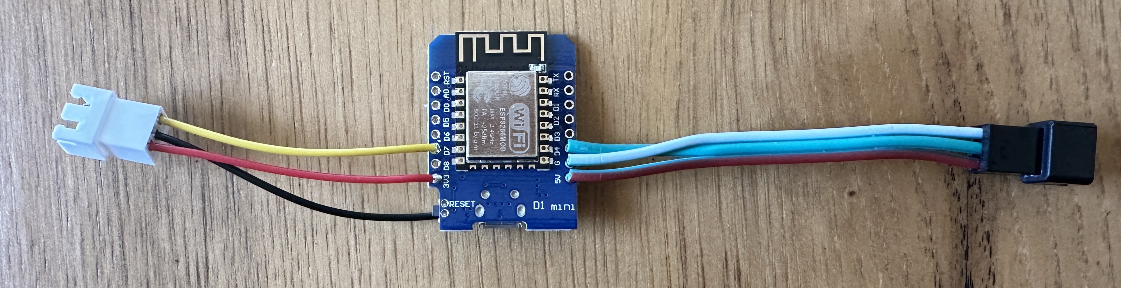
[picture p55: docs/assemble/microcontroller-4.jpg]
    
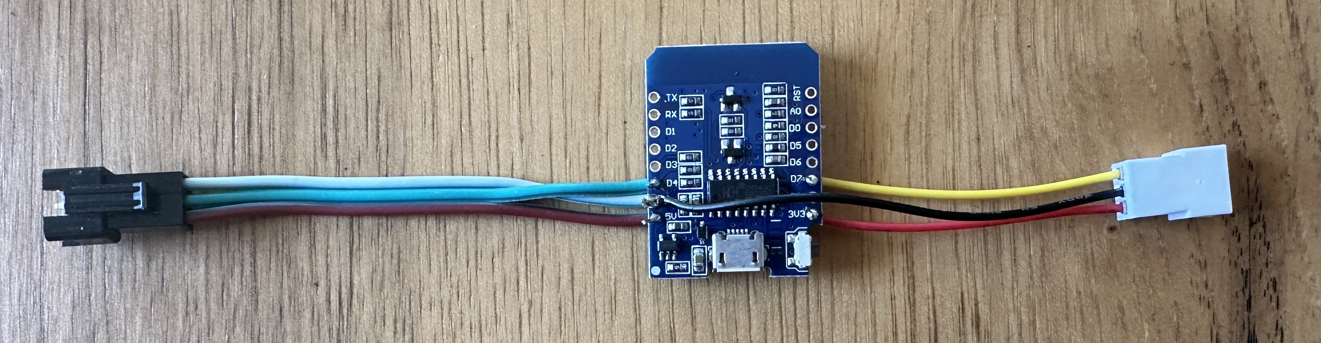
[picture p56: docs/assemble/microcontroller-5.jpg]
    

2. Attach the short micro-usb extension.
    
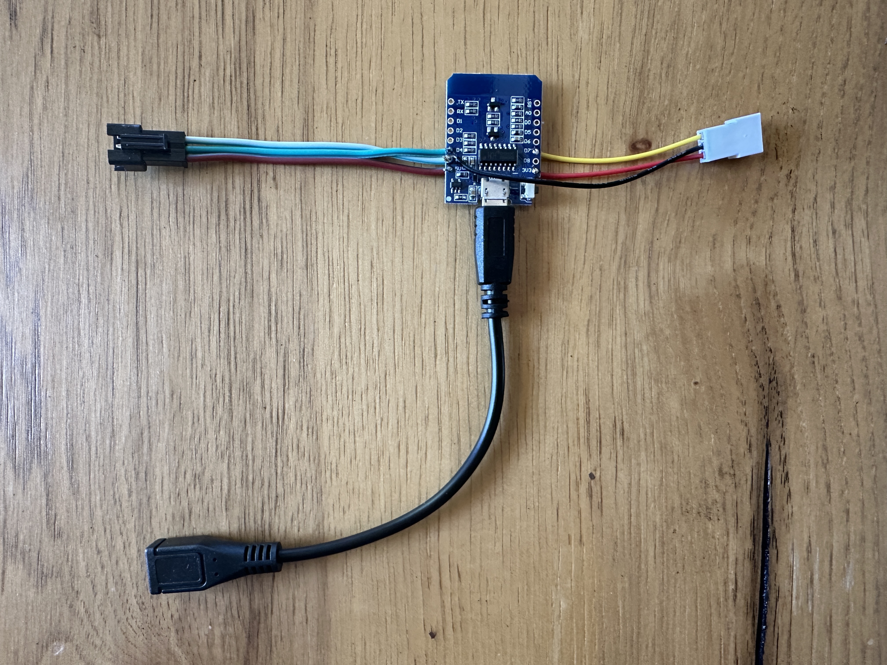
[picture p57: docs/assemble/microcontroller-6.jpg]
    

### Pre-check Testing
1. Connect the LED strip and touch sensor to the microcontroller.
1. Plug in the USB cable to apply power.
1. The LEDs should randomly fade shades of green.

> [!NOTE]
> You must connect the touch sensor. If not, it will believe the touch sensor
is being held down and continuously attempt to turn of the LEDs.

## 3. Main Assembly

### LED Install
1. Starting in the bottom left, remove part of the adhesive tape on the LED
strip and attach to the support wall. Run the lead wire into the ear. Continue
attaching the the LED to the wall similar to the image below.
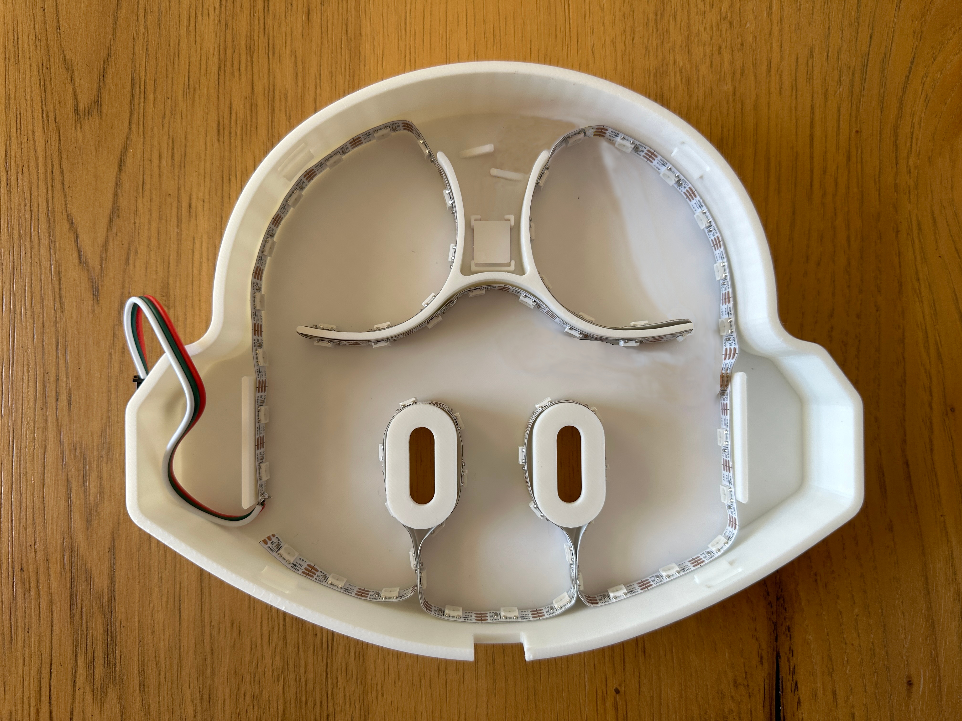
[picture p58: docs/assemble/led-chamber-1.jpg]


1. Insert the touch sensor in the rectangular slot in the forehead area.
Ensuring the touch pad is facing outward. Route the cables between the up between the guides
and to the right.
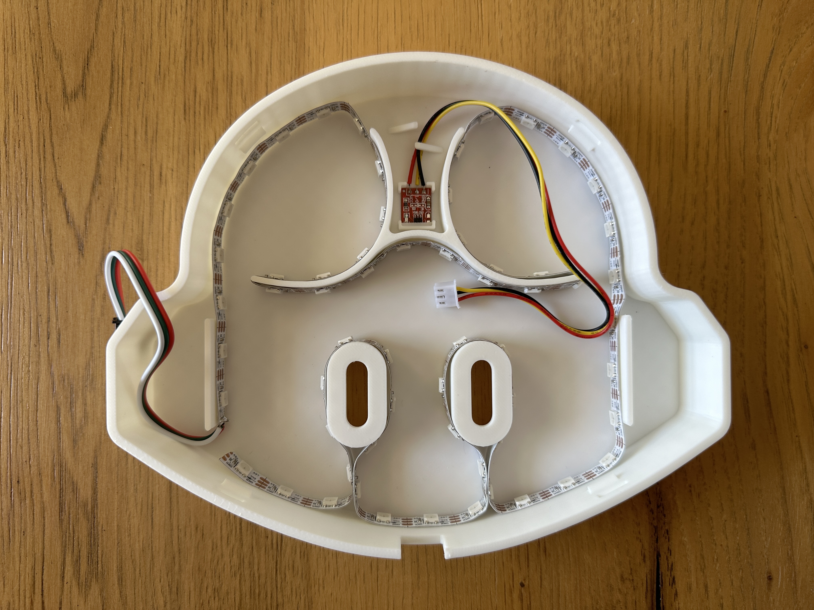
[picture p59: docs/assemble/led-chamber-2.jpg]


### Microcontroller Install
1. Insert the electronics plate.
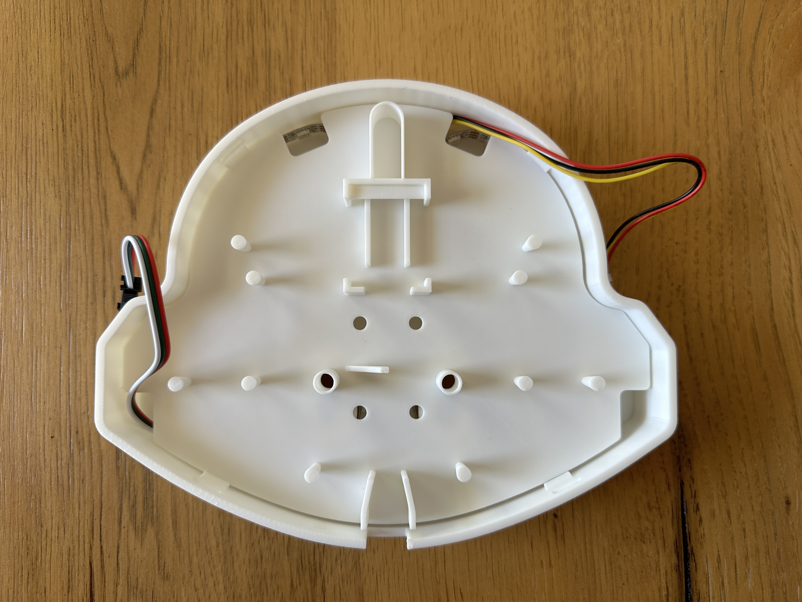
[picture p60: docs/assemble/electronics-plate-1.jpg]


1. Insert the microcontroller into the holder.
Ensure the WiFi module is facing down (toward the face).
Pinch the USB cable under the angled guide bar to secure the microcontroller.
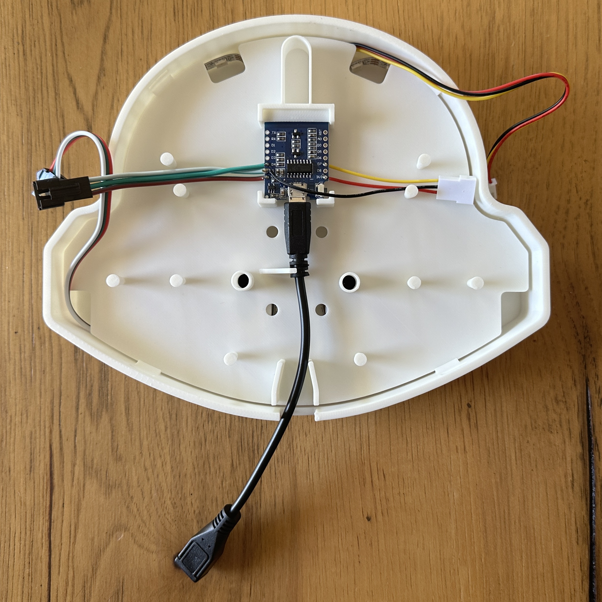
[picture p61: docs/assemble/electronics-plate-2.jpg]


1. Twist the USB cable around some of the left cable guides and pinch it into the holder.
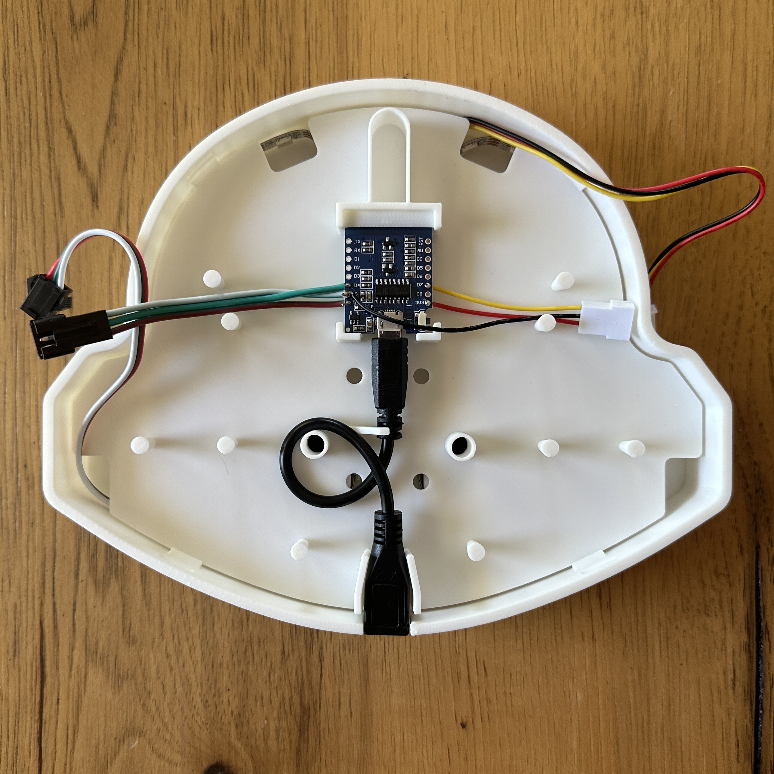
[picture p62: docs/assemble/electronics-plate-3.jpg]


> [!NOTE]  
> You might consider adding a bit of glue behind the usb extension's socket
> to prevent the cable being pulled out. The holes are backup for zip ties
> to hold the USB cable down.

1. Connect the LED cable and touch sensor cables to the microcontroller.
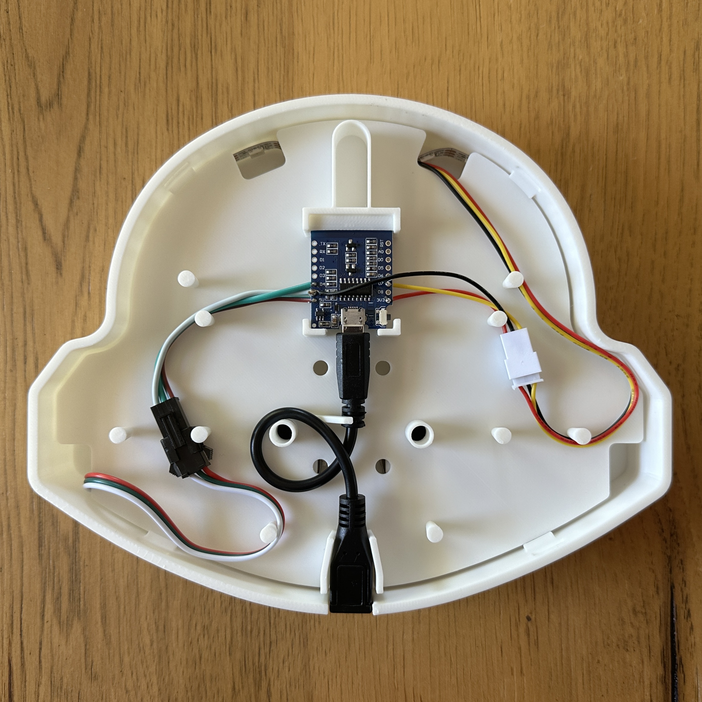
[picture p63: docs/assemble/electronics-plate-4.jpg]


### Cover Plates Install
1. Attach in the backplate by gently pressing it into the LED chamber.


> [!WARNING]  
> Don't apply too much force on the tabs.
> Depending on the filament's brittleness, they might break.

1. Flip the current assembly over.
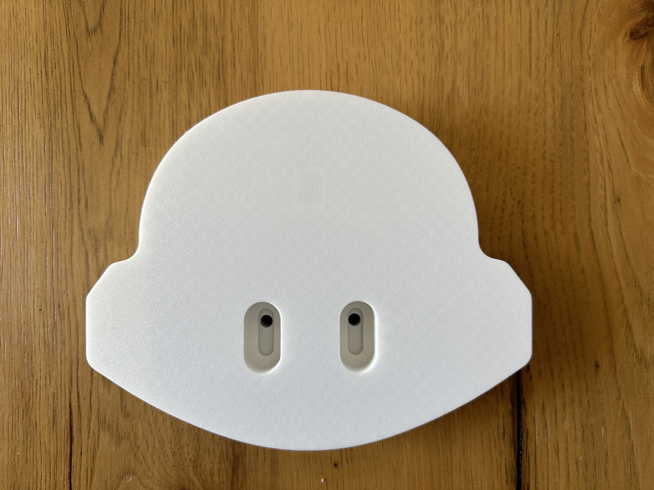
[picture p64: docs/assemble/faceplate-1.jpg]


1. Attach the faceplate by gently sliding it down over the LED chamber.
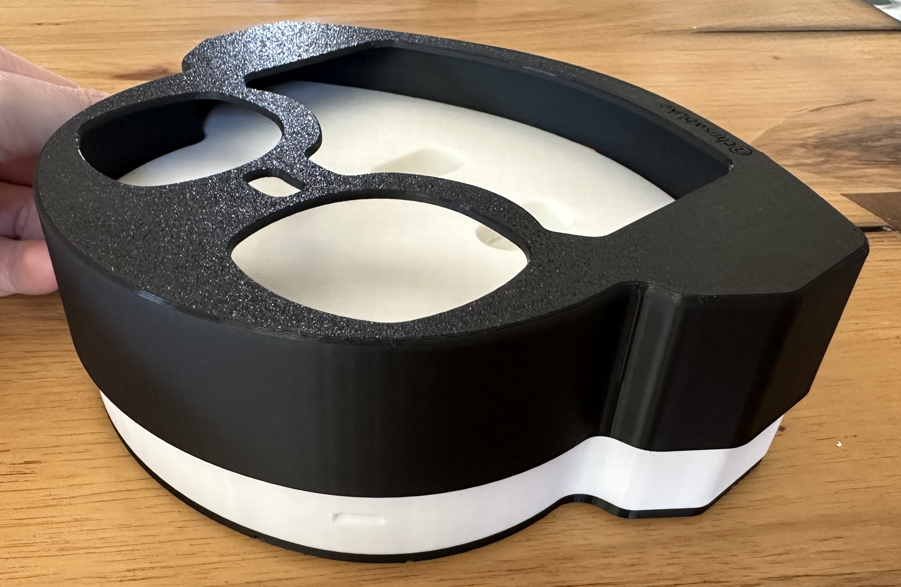
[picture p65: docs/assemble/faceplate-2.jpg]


1. Insert the eyes into the face of the LED chamber.
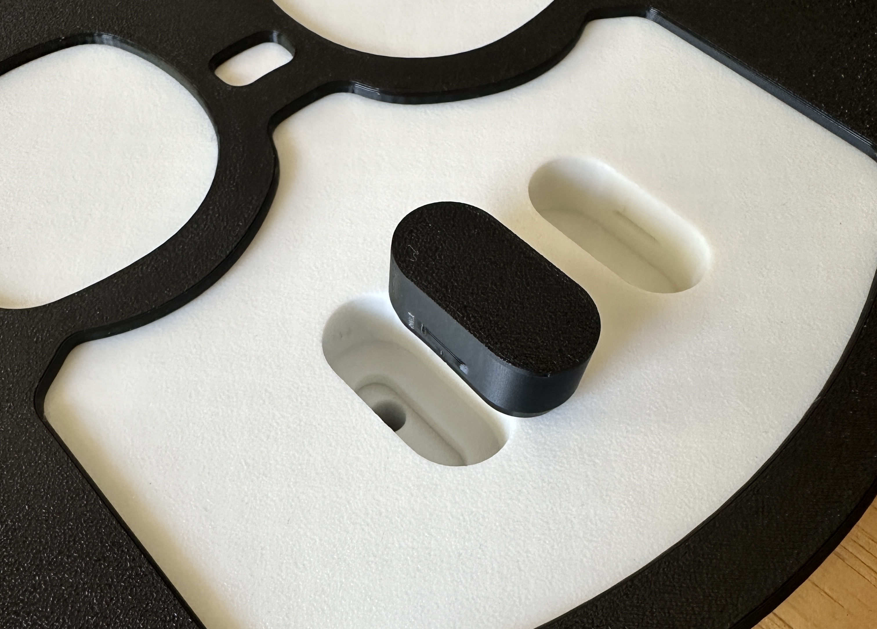
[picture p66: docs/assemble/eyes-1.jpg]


1. You are finished! See the main [README](../README.md) for usage info. Plug it in and enjoy!


## 4. Gift a Friend
Congrats! Nice work! 🎉 Did you have fun making your copilot lamp? I know I did! 🤓

Quick Question. Any chancee you have some extra parts? I bet so.

Why not make another and gift it to a friend. Check out the [gift a friend](/docs/gift-a-friend.md) guide to make sure their unboxing experience is super fantastic! 🦄 💚

## Other Advanced Tasks

### Add your GitHub Handle
If you would like to add your GitHub username, there is already a feature
in the 3d model [`/models/github-copilot-lamp.f3d`](../models/github-copilot-lamp.f3d).
Open it using [Autodesk Fusion](https://www.autodesk.com/products/fusion-360/personal), change the text, and export the STL.

### Switch to USB-C.
- ESP8266 Microcontroller USB-C + WiFi [[US]](https://www.amazon.com/dp/B0BHW1CNCM)
- Short USB-C Extension [[US]](https://www.amazon.com/dp/B01D8FMPP6)

## Troubleshooting

### Reset Device 
- Reset wifi: hold button 0 for >6 seconds.
- Reset WLED: hold button 0 for >12 seconds.

# Reference

## Manually Configure
These are the settings for manually configuring a device the same
as the premade configuration file.

### LED Preferences
- Maximum current: 850mA
- WS281x
- GPIO 2
- Turn LEDs on after power up/reset: unchecked
- Button 0 CPIO: 15 - Push Inverted
- Button 1 CPI: unused - Disabled

### WiFi Setup
DNS address: copilot-lamp.local
AP SSID: copilot-lamp
AP Pass: copilot-lamp
Disable WiFi Sleep: checked

### Time and Macros
Macro Presets Button Actions
- Button 0: short: 0, long: 0, double: 0
- Button 1: short: 1, long: 3, double: 2

### Guides, Manuals, and Tech Specs
- D1 Mini Microcontroller [Pin Detail and Guide](https://diyi0t.com/esp8266-wemos-d1-mini-tutorial)
- D1 Mini [Schematic](ref/D1%20Mini%20schematic.pdf)
- TTP223 Touch Sensor [Video Guide](https://www.youtube.com/watch?v=i0iL5MLXSdU)
- TTP223 Touch Sensor [Tech Specs](ref/D1%20Mini%20schematic.pdf)

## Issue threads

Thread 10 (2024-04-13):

LED Chamber front could be thinner

martinwoodward, 2024-04-13:
Nice work!!  When I was experimenting with the octolamp found that a 0.8mm thickness of the front of the diffuser was enough to diffuse but also let quite a bit of light through without needing any infill support artifacts which always show up when lit.

Also, it's good to include a cut-out at the rear of the device for folks that want to have it on a table / shelf.  I deliberately have a small flat spot at the bottom of the octolamp to support that scenario better too.

Happy to send a PR in with an updated f3d if you wanted to consider these changes, however you are a significantly better 3D CAD designer than me if you were just wanting to bring these in yourself.

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

Note that in my version, I've got rid of the hollow between the goggles to make mine closer to the modern Copilot icon, I don't use the capacitive button though so I haven't tested if the extra thickness of the goggles is too much despite the thinner front to the LED panel.

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

chriswblake, 2024-04-14:
Hi Martin,
Thanks for the feedback. :) I'm happy to see you opened the CAD model and played around with it! :)

Regarding thickness, I also did a bunch of experimenting. Thickness and different infills to create different effects. Ultimately, I liked no infill, but a crosshatch look kinda gave a nice retro vibe. Let me give 0.8mm another check.

Thanks for the thoughts about self standing support. I've created a separate issue (#13) for this change. I'm actually kind of surprised I didn't think about that. Let me play around and see what I can come up with. I'm always open to PRs, but I do want to make sure I keep the faceplate easily modular.

Btw, I have started another issue for the brand compliance (#11). Thanks for sharing the correct png/svg files.

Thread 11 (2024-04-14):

Modify design to use updated branding guidelines

chriswblake, 2024-04-14:
### Problem
The current design uses an outdated design for copilot

### Initial Recommendation
- Match the design in the attached files.
- Replace the goggle strap (hole) with a slight indention to indicate the touch area.

### Attachments
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

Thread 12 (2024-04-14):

Option for WiFi Only (no touch sensor)

chriswblake, 2024-04-14:
### Problem
Not all users will want the touch sensor.

### Recommendation
- Add a WLED configuration file that does not have settings for a touch sensor.
- Add a WLED playlists file that collapses the existing single-press and double-press playlists in to one playlist that starts at power on.

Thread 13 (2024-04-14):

Self Standing Support

chriswblake, 2024-04-14:
### Problem
The USB cable comes directly out of the bottom, and there is no flat area to allow the lamp to be self standing.

### Recommendation
- Shift the USB port to a different location to allow standing on a desk.
- Add a flat or kickstand to help it remain standing.

### Important Considerations
- The faceplate needs to remain modular.
- Assembly should still be simple and intuitive.
- USB cable should be easily connecte/disconnected.

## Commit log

2024-04-04 Add section for materials and tools.
2024-04-05 Add instructions for the printed parts.
    [backplate.stl, electronics-plate.stl, eye.stl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]
2024-04-05 Add pre-assembly instructions for the microcontroller and LED strip.
2024-04-05 Add instructions for installing the LED strip in the LED chamber.
2024-04-05 Add instructions for installing the microcontroller into the LED chamber.
2024-04-05 Add instructions for attaching the faceplate, backplate, and eyes.
2024-04-06 Add gif images for touch button presses
2024-04-06 Add missing Bambu Lab Project (3mf) and Autodesk Fusion model (f3d).
    [gh-copilot-lamp.3mf]
2024-04-06 Add missing instructions for touch sensor.
2024-04-11 Add sections about LED and touch lead cables.
2024-04-11 Updated microcontroller prep pictures to reflect lead cable.
2024-04-11 Updated microcontroller install pictures to reflect lead cable.
2024-04-11 Updated materials area for lead cables.
2024-04-11 Replace picture of LED strip with correct JST connection.
2024-04-11 Include plug JST lead cable in overview picture.
2024-04-13 Add gift guide materials area.
2024-04-13 Add printing area.
    [shipping-protector-left.stl, shipping-protector-right.stl]
2024-04-13 Update CAD models to include original shipping protector designs.
    [gh-copilot-lamp.3mf]
2024-04-13 Add draft instructions for assembly and packing. No pictures yet.
2024-04-13 Add references for microcontroller and touch sensor.
2024-05-26 Add missing parts in materials area.
2024-10-20 Easier to remove eye (#15)
    * Reduce eye thickness to 1mm
    * Mention thicker eye option in docs
    [eye-2mm.stl, eye.stl, gh-copilot-lamp.3mf]
